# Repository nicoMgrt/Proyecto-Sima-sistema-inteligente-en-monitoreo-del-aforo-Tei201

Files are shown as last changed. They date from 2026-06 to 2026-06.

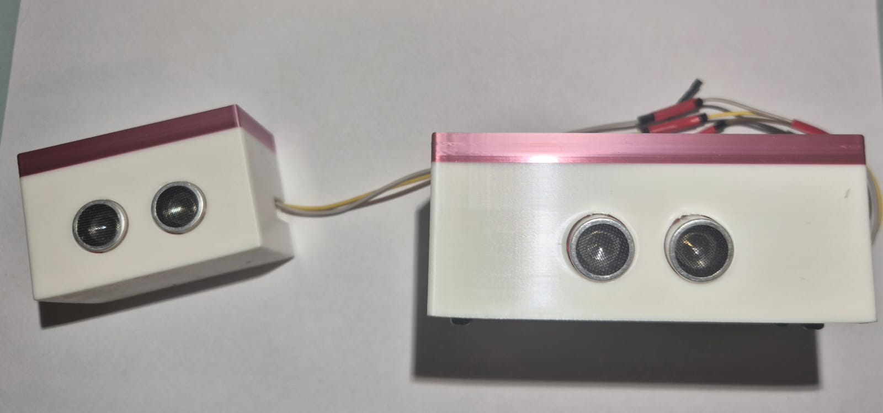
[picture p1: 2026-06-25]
testing/evidencias/prototipo_frontal_01.jpg (2).jpeg

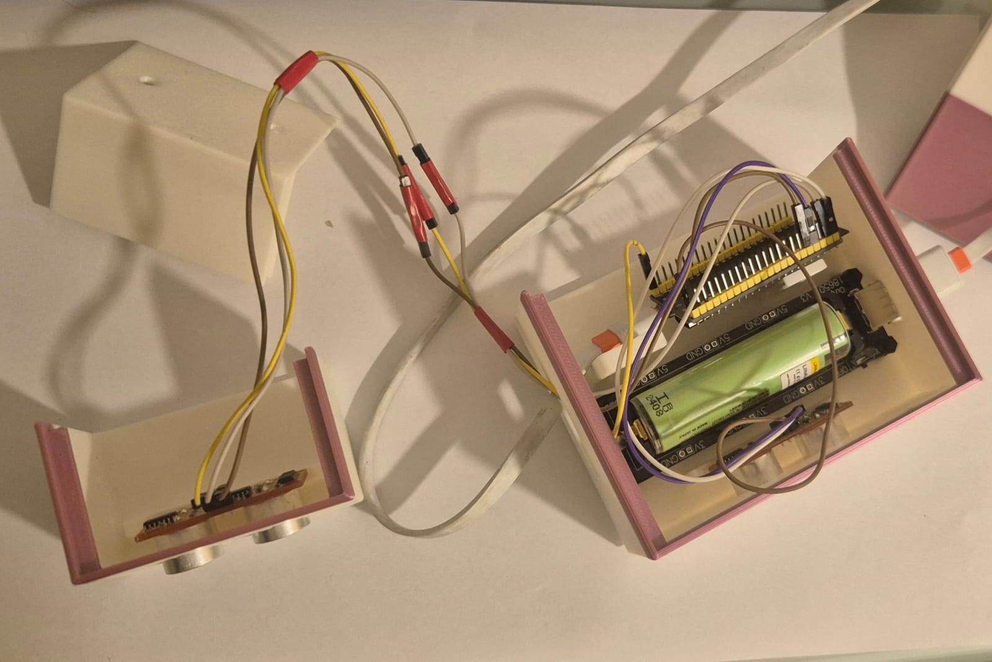
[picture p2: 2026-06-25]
hardware/fotos/01_vista_general.jpeg

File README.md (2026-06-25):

# SIMA — Sistema Inteligente de Monitoreo de Aforo

Sistema IoT que monitorea el aforo de la Biblioteca de Pregrado de la UAI en tiempo real, detectando entradas y salidas mediante dos sensores ultrasónicos y determinando la dirección del flujo según el orden de activación. Precisión global validada: **91,4% en 35 pruebas controladas.**

---

## Equipo

| Integrante | Rol principal | GitHub |
|---|---|---|
| Nicolás Marinkovic Grant | Iteraciones · Documentación · Testing | [@nicoMgrt](https://github.com/nicoMgrt) |
| Bárbara Chaparro Torres | Software · Firmware · Documentación | [@barbarachaparro](https://github.com/barbarachaparro) |
| Valentina Ramírez Gómez | Diseño 3D · Iteraciones | [@valenramirez-Hub](https://github.com/valenramirez-Hub) |
| Cristóbal Pérez | Hardware · Software · Diseño 3D | [@CPerex](https://github.com/CPerex) |

---

## Descripción del Problema

Los estudiantes de la Universidad Adolfo Ibáñez no tienen forma de saber si hay espacio disponible en la Biblioteca de Pregrado antes de desplazarse. Una encuesta a 69 estudiantes (Avance #1, marzo 2026) reveló que el **74,2% ha tenido que abandonar la biblioteca por falta de espacio** y el **39,7% pierde entre 5 y más de 10 minutos buscando asiento en hora peak** (bloques M3–M5).

SIMA resuelve esta brecha entregando el porcentaje de ocupación en tiempo real, accesible desde cualquier dispositivo en la misma red, antes de que el estudiante se desplace.

*Proyecto enmarcado en el ODS 11 — Ciudades y Comunidades Sostenibles · Avance #1 TEI201, 2026.*

---

## Solución — Arquitectura del Sistema IoT

```
Sensor A (pasillo exterior, GPIO4)
Sensor B (interior biblioteca, GPIO5)
         ↓
     ESP32-S3
(detección direccional + FreeRTOS dual-core)
         ↓
  Google Apps Script (HTTPS)
         ↓
  Google Sheets (histórico persistente)
         ↓
  Google Looker Studio (dashboard con gráficas)
         +
  Dashboard web local (IP del dispositivo, cada 3 seg)
```

El sistema detecta si una persona **entra o sale** según qué sensor se activa primero. La arquitectura FreeRTOS separa la detección (Core 1) del envío HTTP (Core 0), garantizando que el sistema siga midiendo aunque el envío a Sheets tome hasta 3 segundos.

**El prototipo se compone de dos módulos físicos** conectados por cable: el módulo principal (ESP32-S3 + batería + sensor B) y el módulo secundario (sensor A), instalados en lados opuestos del marco de la puerta para maximizar la separación entre sensores y mejorar la detección direccional.

---

## Componentes de Hardware

| Componente | Cantidad | Especificación | Costo |
|---|---|---|---|
| ESP32-S3 Dev Module | 1 | Dual-core Xtensa LX7 240MHz, WiFi 2.4GHz, 512KB SRAM | $6.990 |
| HC-SR04 Seeed Grove (3 pines) | 2 | 3.3V nativo, rango 3–350cm, GPIO4 y GPIO5 | $9.980 |
| Batería NCR18650B Panasonic | 1 | Li-ion 3.7V, 3.400mAh, autonomía ~16–20h | $2.000 |
| Shield cargador 18650 | 1 | Micro-USB entrada, USB-A salida 5V/1A, boost converter | $3.990 |
| Cable USB-A a USB-C | 1 | 30cm, conexión shield → ESP32-S3 (COM/UART) | $1.990 |
| Jumper wires M-M | 1 set | 20cm, 40 unidades | $1.490 |
| Protoboard 400 puntos | 1 | Conexión sin soldadura | $1.990 |
| Filamento PLA | ~50g | Encapsulado impreso en 3D | $5.000 |
| **TOTAL** | | | **$27.960 CLP** |

---

## Instrucciones de Uso

### 1. Cargar el firmware

1. Abre `software/src/main.ino` en **Arduino IDE 2.x**
2. Instala el soporte ESP32: Board Manager → buscar **ESP32 by Espressif** → instalar
3. Las librerías (`WiFi.h`, `WebServer.h`, `Preferences.h`, `HTTPClient.h`, `time.h`) vienen incluidas con el core de ESP32 — no requieren instalación adicional
4. Edita las credenciales WiFi:
   ```cpp
   const char* ssid     = "TU_RED_WIFI";
   const char* password = "TU_CONTRASEÑA";
   ```
5. Ajusta el aforo máximo si es necesario:
   ```cpp
   #define AFORO_MAX  295
   ```
6. Selecciona la placa **ESP32S3 Dev Module** (no ESP32 genérico) y el puerto **COM/UART**
7. Sube el código con **Upload**

### 2. Conectar los sensores

| Sensor | GPIO | Ubicación |
|---|---|---|
| Sensor A | GPIO 4 | Lado pasillo exterior |
| Sensor B | GPIO 5 | Lado interior de la biblioteca |

Alimentación de ambos sensores: **3.3V y GND** del ESP32-S3.

### 3. Ver el dashboard local

1. Abre el **Monitor Serial** (115200 baudios) tras cargar el firmware
2. Espera: `¡Conectado! IP: 192.168.X.X`
3. Ingresa esa IP desde cualquier navegador en la misma red
4. El dashboard se actualiza automáticamente cada 3 segundos — muestra % de ocupación, estado (Disponible / Casi lleno / Lleno) y contadores de entradas/salidas del día

### 4. Reset manual del contador (operadores)

Accede desde un navegador en la misma red:
```
http://[IP_DEL_DISPOSITIVO]/admin-reset-biblioteca
```

### 5. Ver los datos históricos

- 📊 **Google Sheets:** [Ver registro de eventos](https://docs.google.com/spreadsheets/d/TU_ID_DE_SCRIPT)
- 

---

## Resultados de Validación

| Prueba | Casos | Tasa de éxito |
|---|---|---|
| Detección de entrada (A→B) | 10 | 90% |
| Detección de salida (B→A) | 10 | 80% |
| Anti-bloqueo timeout (2.000ms) | 5 | 100% |
| Persistencia ante corte de energía | 5 | 100% |
| Envío a Google Sheets (HTTP 200 OK) | 5 | 100% |
| **Precisión global** | **35** | **91,4%** |

---

## Estructura del Repositorio

```
SIMA-contador-personas-TEI201/
├── README.md                        ← Este archivo
├── FUENTES.md                       ← Declaración de librerías, código externo e IA
│
├── software/
│   ├── src/                         ← Firmware principal (main.ino)
│   ├── librerias/                   ← Documentación de librerías utilizadas
│   └── docs/                        ← Diagramas de flujo y documentación técnica
│
├── hardware/
│   ├── esquematico.pdf              ← Diagrama de conexiones del circuito
│   ├── BOM.xlsx                     ← Lista de componentes con costos
│   ├── datasheets.pdf               ← Especificaciones técnicas de componentes
│   └── fotos/                       ← Fotografías del prototipo (3+ ángulos)
│
├── diseno_3d/
│   ├── fusion360/                   ← Archivo .f3d del ensamble completo
│   ├── planos/                      ← Planos técnicos con cotas en PDF
│   └── renders/                     ← Renders exterior, interior y explosionado
│
├── testing/
│   ├── datos/                       ← Exportación Google Sheets + resultados de pruebas
│   ├── evidencias/                  ← Fotos y capturas del prototipo en operación
│   └── reportes/                    ← Protocolo de pruebas completo (PDF)
│
├── documentacion/
│   ├── presentacion/                ← Slides de la presentación final (PPTX/PDF)
│   └── reporte_final/               ← Reporte final del proyecto (PDF, 12 páginas)
│
└── iteraciones/
    ├── iteracion_1/                 ← v1 Alpha — Abril 2026
    ├── iteracion_2/                 ← v2 Beta — Mayo 2026
    └── iteracion_3/                 ← v4 Final — Junio 2026
```

---

## Estado del Proyecto

- [x] Firmware con detección direccional entrada/salida (FreeRTOS dual-core)
- [x] Dashboard web local en tiempo real (semáforo + estadísticas diarias)
- [x] Envío de datos a Google Sheets (HTTP 200 OK confirmado)
- [x] Persistencia ante cortes de energía (NVS flash — 5/5 reinicios ✓)
- [x] Encapsulado modelado en Fusion 360 con gemelo digital completo
- [x] Protocolo de pruebas documentado (91,4% precisión global)
- [x] Reporte final del proyecto (12 páginas)
- [x] Fotos del prototipo (3 ángulos)
- [ ] Google Looker Studio — en desarrollo
- [ ] Planos técnicos PDF exportados desde Fusion 360
- [ ] Renders finales del encapsulado

---

*TEI201 — Taller de Diseño en Ingeniería · Universidad Adolfo Ibáñez · 2026*
*Proyecto SIMA — Marinkovic · Chaparro · Ramírez · Pérez*

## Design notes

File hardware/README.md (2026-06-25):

# Hardware - Documentación

## Contenido
Esta carpeta contiene toda la documentación técnica del hardware del proyecto.

## 📁 Carpetas

### esquemas/
Diagramas de circuitos y esquemáticos del sistema
- `wokwi_diagram.json` — Archivo fuente del circuito en Wokwi
- `wokwi_screenshot.png` — Captura del circuito completo
- `wokwi_link.txt` — Link al proyecto online en Wokwi

### bom/
Bill of Materials (Lista de materiales)
- `BOM_contador_biblioteca.xlsx` — BOM editable con fórmulas
- `BOM_contador_biblioteca.pdf` — BOM en PDF para presentación
- `datasheets/` — Datasheets de componentes críticos

### fotos/
Fotografías de alta resolución del prototipo ensamblado
- `01_vista_general.jpg`
- `02_circuito_interno.jpg`
- `03_detalle_conexiones.jpg`
- `04_sensores.jpg`
- `05_shield_bateria.jpg`
- `06_encapsulado_cerrado.jpg`
- `07_contexto_uso.jpg`

---

## Componentes Principales

| Componente | Función |
|---|---|
| ESP32-S3 Dev Module | Microcontrolador principal — procesa sensores, sirve la página web y envía datos a Google Sheets |
| Sensor Ultrasónico Seeed Grove x2 | Detección de personas — sensor A (pasillo) y sensor B (biblioteca) |
| Batería Li-ion NCR18650B | Fuente de energía portátil — 3400mAh reales, autonomía ~16-20 horas |
| Shield Cargador 18650 con USB-A | Gestión de batería — boost converter 3.7V→5V, protección y carga integrada |
| Protoboard 400 puntos | Conexión de sensores a la ESP32-S3 sin soldadura |

---

## Pasos de Ensamblaje

1. Conectar el sensor A al GPIO4 de la ESP32-S3: VCC→3.3V, GND→GND, SIG→GPIO4
2. Conectar el sensor B al GPIO5 de la ESP32-S3: VCC→3.3V, GND→GND, SIG→GPIO5
3. Insertar la batería NCR18650B en el shield cargador
4. Conectar el shield a la ESP32-S3 mediante cable USB-A a USB-C en el puerto COM/UART
5. Configurar el firmware con las credenciales WiFi y URL del Google Apps Script
6. Instalar los sensores en la puerta: sensor A en el lado del pasillo, sensor B en el lado de la biblioteca, separados por el ancho de la puerta

---

## Precauciones

⚠️ Usar siempre el puerto COM/UART para programar y alimentar la ESP32-S3, NUNCA el puerto USB nativo — causa inestabilidad con WiFi+HTTPS activos simultáneamente

⚠️ Los sensores Seeed Grove operan a 3.3V — conectar siempre al pin 3.3V de la ESP32-S3, NUNCA al pin 5V para evitar dañar la placa

⚠️ No conectar ni desconectar los sensores con el sistema encendido (hot-plug) — puede dañar el sensor permanentemente

⚠️ La batería NCR18650B no debe descargarse bajo 2.5V — el shield incluye protección, pero evitar dejar el sistema encendido sin supervisión cuando la batería está baja

---

## Especificaciones Técnicas

| Parámetro | Valor |
|---|---|
| Alimentación | 3.7V batería Li-ion → 5V regulado por shield |
| Consumo promedio | ~80-100 mA (WiFi modem sleep activo) |
| Consumo peak | ~240 mA (durante transmisión WiFi) |
| Autonomía estimada | 16-20 horas con NCR18650B (3400 mAh) |
| Dimensiones encapsulado | 125 x 75 x 50 mm |
| Rango sensores | 3 cm – 350 cm (umbral configurado: 40 cm) |
| Frecuencia de muestreo | Cada 100 ms |

---

## Troubleshooting

| Problema | Posible Causa | Solución |
|---|---|---|
| ESP32 no aparece en puertos | Usando el puerto USB nativo | Cambiar al puerto COM/UART (el otro conector) |
| Sensores no detectan | GPIO incorrecto o cables sueltos | Verificar GPIO4 y GPIO5, revisar conexiones en protoboard |
| Contador no sube al pasar la mano | Objeto estático frente a un sensor | Alejar obstáculos, verificar que "Sensor bloqueado" no aparezca en Serial Monitor |
| No envía datos a Sheets | HTTP 400 o sin WiFi | Verificar credenciales WiFi y URL del script en el código |
| ESP32 en boot loop | Board incorrecto en Arduino IDE | Seleccionar ESP32S3 Dev Module, hacer erase flash |

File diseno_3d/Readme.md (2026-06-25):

# Diseño 3D - Documentación

## ⚠️ REQUISITO CRÍTICO

El modelo 3D debe incluir **TODOS** los componentes del prototipo:
- ✅ Encapsulado exterior completo
- ✅ Placa ESP32/Arduino (con dimensiones exactas)
- ✅ Todos los sensores en posición de instalación
- ✅ Todos los actuadores
- ✅ Batería / fuente de alimentación
- ✅ Cableado (routing aproximado)
- ✅ Sistema de montaje (brackets, tornillos)
- ✅ Orificios de ventilación (si aplica)

**NO ES ACEPTABLE:** Solo el encapsulado vacío sin componentes internos

---

## Carpetas

#### `fusion360/`
Archivos nativos de Fusion 360 (.f3d)

#### `renders/`
Imágenes renderizadas de alta calidad

#### `planos/`
Planos técnicos con cotas

---

## Especificaciones

**Software:** Autodesk Fusion 360  
**Unidades:** Milímetros (mm)  
**Escala:** 1:1 (dimensiones reales)

**Dimensiones externas:** Caja chica: [41.358 mm × 46 mm × 68.181 mm]  Caja grande: [80.358 mm x 46 mm x 108.181 mm]

**Peso estimado:** [133 gramos]  
**Material:** PLA

---

## Consideraciones de Diseño

### Funcionales
- [ ] Acceso a puertos USB/alimentación
- [ ] Ventilación adecuada
- [ ] Protección de componentes
- [ ] Fácil acceso para mantenimiento
- [ ] Resistencia a condiciones ambientales

### Fabricación
- [ ] Imprimible sin soportes excesivos
- [ ] Tolerancias de ensamble (+0.2mm)
- [ ] Grosor de pared mínimo 2mm
- [ ] Sin ángulos imposibles (overhangs <45°)

---

## Configuración de Impresión 3D (si fue utilizada)

**Impresora:** [Modelo: Bambu Lab A1 ]  
**Material:** [PLA]  
**Calidad de capa:** 0.2mm  
**Relleno:** 8%  
**Soportes:** [Sí - En las áreas donde el ángulo de impresión supera los 45° y hay voladizo]  
**Temperatura nozzle:** [210°C]  
**Temperatura cama:** [65 °C]  
**Velocidad:** [200 mm/s]

**Tiempo estimado de impresión:** [8 horas]  
**Tiempo estimado de impresión:** [2 horas caja chica y 5 horas caja grande]  
**Peso de material:** [133 gramos]

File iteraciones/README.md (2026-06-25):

# Historial de Iteraciones — SIMA

## Propósito

Esta carpeta documenta la evolución del sistema SIMA a través de sus tres versiones de desarrollo. El proceso iterativo fue fundamental para resolver problemas reales de hardware, conectividad y algoritmo que no eran predecibles en el diseño inicial.

---

## Estructura de Carpetas

```
iteraciones/
├── iteracion_1/    # v1 Alpha — Prueba de concepto en laboratorio (Abril 2026)
├── iteracion_2/    # v2 Beta — Primera mejora significativa (Mayo 2026)
└── iteracion_3/    # v4 Final — Sistema completo y validado (Junio 2026)
```

Cada carpeta contiene: `README.md` con descripción completa de la versión, fotos del prototipo, esquema del circuito, código fuente y notas de laboratorio.

---

## Tabla Comparativa de Iteraciones

| Aspecto | v1 Alpha | v2 Beta | v4 Final |
|---|---|---|---|
| **Fecha** | Abril 2026 | Mayo 2026 | Junio 2026 |
| **Sensores** | HC-SR04 4 pines (5V) ❌ | Seeed Grove 3 pines (3.3V) ✅ | Seeed Grove 3.3V ✅ |
| **GPIO sensores** | Sin definir | GPIO1/GPIO10 ⚠️ | GPIO4/GPIO5 ✅ |
| **Conectividad** | Red UAI (bloqueada) ❌ | AP autónomo ✅ | Router + Google Sheets ✅ |
| **Almacenamiento** | Sin persistencia ❌ | Sin persistencia ❌ | NVS flash + Sheets ✅ |
| **Autonomía** | USB (sin batería) ❌ | ~6h (NCR18650B) ✅ | ~16–20h (modem sleep) ✅ |
| **Falsos positivos** | Sí ❌ | No ✅ | No (<5%) ✅ |
| **Dashboard** | Web básico | Semáforo dinámico | Semáforo + estadísticas diarias |
| **Encapsulado** | Sin encapsulado ❌ | Boceto Fusion 360 | Gemelo 3D completo ✅ |
| **Envío a nube** | No ❌ | No ❌ | Google Sheets (HTTP 200 OK) ✅ |
| **Precisión global** | Sin medir | 4.8/5 (subjetivo) | 91.4% (35 pruebas) ✅ |
| **Funcionalidad** | ~40% | ~70% | 100% ✅ |

---

## Evolución del Diseño

### v1 Alpha — Concepto Inicial (Abril 2026)
**Estado:** Prueba de concepto en laboratorio

El primer prototipo validó la factibilidad técnica básica: servidor web embebido en el ESP32-S3 y detección cruda de presencia con sensores ultrasónicos. Sin embargo, identificó tres problemas críticos que bloqueaban el funcionamiento real: incompatibilidad de voltaje entre sensores HC-SR04 (5V) y los GPIO del ESP32-S3 (3.3V), bloqueo de la red WiFi institucional por portal cautivo, y falsos positivos cuando una persona se detenía frente a los sensores.

### v2 Beta — Primera Mejora Significativa (Mayo 2026)
**Estado:** Prototipo funcional mejorado

Resolvió los tres problemas críticos de v1. Migró a sensores Seeed Grove de 3 pines compatibles con 3.3V, implementó modo Access Point autónomo para independizarse de la red UAI, y desarrolló el algoritmo de secuencia estricta con anti-rebote. Incorporó autonomía energética con Battery Shield + celda NCR18650B y el primer dashboard web con semáforo visual. Problema pendiente: sin persistencia de datos ante cortes de energía, y envío bloqueante que congelaba la detección.

### v4 Final — Sistema Completo (Junio 2026)
**Estado:** Sistema IoT completo y validado — listo para presentación

Implementó el ciclo completo de datos con arquitectura FreeRTOS dual-core (Core 1 detección, Core 0 HTTP), persistencia NVS con `Preferences.h`, integración HTTPS con Google Sheets y Google Looker Studio, reset automático nocturno por tiempo de inactividad, y encapsulado completo en Fusion 360. Precisión global validada en 35 pruebas: 91.4%.

---

## Justificación de Cambios

### Hardware

**De v1 a v2:**
- Cambio: HC-SR04 4 pines → Seeed Grove 3 pines
- Razón: Los HC-SR04 operan a 5V — riesgo de dañar permanentemente los GPIO del ESP32-S3 que soportan 3.3V máximo
- Impacto: Compatibilidad nativa, cableado simplificado con pin SIG único

**De v2 a v4:**
- Cambio: GPIO1/GPIO10 → GPIO4/GPIO5
- Razón: GPIO1 es TX del UART0 y GPIO10 está mapeado al SPI interno — causaban boot loop crítico al agregar HTTPS
- Impacto: Eliminación total del boot loop, sistema completamente estable

### Software

**De v1 a v2:**
- Algoritmo anti-rebote: conteo consolidado solo cuando `!detectaA && !detectaB`
- Modo Access Point autónomo (`WiFi.softAP`) para independizarse del portal cautivo UAI
- Dashboard web HTML/CSS con semáforo dinámico de aforo

**De v2 a v4:**
- FreeRTOS dual-core: detección en Core 1, HTTP en Core 0 — elimina latencia bloqueante
- Persistencia NVS con `Preferences.h` — contador sobrevive cortes de energía (5/5 reinicios ✓)
- Integración HTTPS Google Sheets con timestamp ISO 8601 — HTTP 200 OK confirmado
- Timeout anti-bloqueo de 2.000ms — previene conteos fantasma
- Reset automático nocturno si apagado >2 horas
- WiFi modem sleep — autonomía extendida de ~6h a ~16–20h

### Diseño 3D

**De v1 a v2:**
- Primer boceto de encapsulado en Fusion 360 con distribución interna "sándwich"
- Aberturas frontales para transductores de los sensores Seeed

**De v2 a v4:**
- Gemelo 3D completo con todos los componentes internos a dimensiones reales
- Tapa desmontable sin destruir el ensamble (diseño para reparación en campo)
- Orificios laterales para micro USB y switch de encendido
- Postes espaciadores M3 internos

---

## Incorporación de Feedback

### Feedback del Avance #1 → Cambios en v2
- *"El sistema debe ser autónomo energéticamente para instalarse en terreno"*
  - Acción: Battery Shield V3 + celda NCR18650B Panasonic 3400mAh

### Feedback del Avance #2 → Cambios en v4
- *"Los datos generados se pierden y no se aprovechan para decisiones a largo plazo"*
  - Acción: Integración Google Sheets con registro histórico de cada evento con timestamp
- *"¿Qué ocurre si alguien bloquea la puerta intencionalmente varios segundos?"*
  - Acción: Timeout anti-bloqueo de 2.000ms implementado y validado en pruebas

### Feedback de Testing → Cambios en v4
- *"El sistema no detectaba personas delgadas o que cruzaban por el centro del marco"*
  - Acción: Umbral de detección elevado de 30cm a 40cm

---

## Métricas de Mejora

| Métrica | v1 Alpha | v2 Beta | v4 Final | Mejora total |
|---|---|---|---|---|
| Compatibilidad eléctrica | Riesgo de quema | Estable 3.3V | Estable 3.3V | ✅ Resuelto |
| Latencia envío datos | Sin envío | Sin envío | 1.5–3 seg (no bloqueante) | ✅ Nuevo |
| Autonomía batería | Sin batería | ~6h | ~16–20h | ↑ +300% |
| Tasa de falsos positivos | Alta | <5% | <5% | ↓ ~90% |
| Persistencia ante corte energía | No | No | 100% (5/5) | ✅ Nuevo |
| Precisión detección global | Sin medir | 4.8/5 (subjetivo) | 91.4% (35 pruebas) | ✅ Validado |
| Almacenamiento histórico | No | No | Google Sheets ilimitado | ✅ Nuevo |

---

## Lecciones Aprendidas

### Técnicas
1. Verificar siempre los niveles lógicos de voltaje (3.3V vs 5V) antes de conectar módulos — la incompatibilidad puede dañar hardware irreversiblemente
2. Los GPIO con funciones reservadas del chip (UART, SPI, USB) no deben usarse para sensores que cambien constantemente su dirección
3. Las llamadas HTTP síncronas bloquean el loop principal en IoT — FreeRTOS es la solución correcta para concurrencia en ESP32-S3

### De Proceso
1. La prueba de concepto mínima (v1) es indispensable — identifica problemas reales que el diseño en papel no predice
2. Documentar cada falla y su solución en tiempo real facilita la elaboración del FUENTES.md y el protocolo de testing al final del proyecto

### De Trabajo en Equipo
1. Dividir el trabajo por componentes (hardware, software, diseño 3D, documentación) permite avanzar en paralelo sin bloquear al equipo
2. Comunicar los cambios de hardware al equipo de software inmediatamente evita que dos personas trabajen sobre supuestos distintos

---

*TEI201 — Taller de Diseño en Ingeniería · Universidad Adolfo Ibáñez · 2026*
*Proyecto SIMA — Nicolás Marinkovic · Bárbara Chaparro · Valentina Ramírez · Cristóbal Pérez*

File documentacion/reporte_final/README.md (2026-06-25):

# SIMA — Sistema Inteligente de Monitoreo de Aforo
## Reporte Final del Proyecto

**ODS 11 — Ciudades y Comunidades Sostenibles**

| Integrante | Rol |
|---|---|
| Nicolás Ignacio Marinkovic Grant | Iteraciones / Documentación / Testing |
| Bárbara Carolina Chaparro Torres |  Software / Firmware / Dcumentación |
| Valentina Paz Ramírez Gómez | Iteraciones / Diseño 3D |
| Cristóbal Pérez | Harware/ Software / Diseño 3D |

**Taller de Diseño en Ingeniería — TEI201**
Design Engineering Center · Universidad Adolfo Ibáñez · Junio 2026

---

## Resumen Ejecutivo

El sistema SIMA (Sistema Inteligente de Monitoreo de Aforo) es un dispositivo IoT de bajo costo diseñado para proveer información de ocupación en tiempo real de la Biblioteca de Pregrado de la Universidad Adolfo Ibáñez, Campus Peñalolén. El sistema resuelve una brecha de información identificada mediante encuesta a 69 estudiantes: el 74,2% ha tenido que abandonar la biblioteca por falta de espacio y el 39,7% pierde entre 5 y más de 10 minutos buscando un asiento disponible en hora peak.

La solución integra dos sensores ultrasónicos Seeed Grove conectados a un microcontrolador ESP32-S3, que determina la dirección del flujo de personas según el orden de activación de los sensores. Los datos se almacenan en Google Sheets y se visualizan en un dashboard web local con indicador semafórico de ocupación. El costo total del prototipo es de $27.960 CLP, con una precisión global validada de 91,4% en 35 pruebas controladas y autonomía de 16 a 20 horas continuas.

**Conclusión clave:** SIMA demuestra que es posible optimizar el uso de infraestructura educativa existente mediante tecnología IoT de bajo costo, sin expansión física y respetando la privacidad de los usuarios, en alineación con el ODS 11.

---

## 1. Introducción

### 1.1 Contexto General

La Universidad Adolfo Ibáñez en el Campus Peñalolén concentra más de 8.000 estudiantes diarios que compiten por espacios de estudio. La Biblioteca de Pregrado, con una capacidad estimada de 295 personas, opera sin ningún sistema de monitoreo de aforo, lo que genera una asimetría de información que afecta directamente la experiencia académica del estudiantado.

### 1.2 Problemática ODS Específica

El proyecto se enmarca en el ODS 11 (Ciudades y Comunidades Sostenibles), específicamente en la meta de optimizar el uso de infraestructura existente antes de recurrir a la expansión física. A través de una encuesta a 69 estudiantes del campus (Avance #1, marzo 2026) se cuantificó la magnitud del problema:

- El **74,2%** de los encuestados se ha visto forzado a abandonar la biblioteca por falta de espacio
- El **39,7%** pierde entre 5 y más de 10 minutos buscando un asiento disponible
- El **50,7%** asiste en bloque M3 (11:30), el horario de mayor saturación
- El **59,4%** reporta contaminación acústica en horas peak

### 1.3 Objetivos del Proyecto

- Desarrollar un sistema IoT de detección direccional de personas para monitoreo de aforo en tiempo real
- Almacenar los datos de ocupación en una plataforma accesible con histórico persistente
- Visualizar la información mediante un dashboard que permita tomar decisiones informadas
- Diseñar un encapsulado funcional para instalación en condiciones reales de operación

### 1.4 Alcance

El prototipo SIMA está diseñado para la entrada principal de la Biblioteca de Pregrado, Campus Peñalolén, UAI. Opera en entorno de red WiFi local, es autónomo energéticamente con batería recargable y no requiere intervención manual para su operación cotidiana. El sistema es replicable a otros espacios de acceso controlado del campus.

---

## 2. Marco Teórico y Estado del Arte

### 2.1 ODS 11 — Ciudades y Comunidades Sostenibles

El Objetivo de Desarrollo Sostenible 11 propone hacer las ciudades y los asentamientos humanos inclusivos, seguros, resilientes y sostenibles. En el contexto universitario, esto se traduce en la gestión inteligente de espacios educativos: maximizar la utilidad de la infraestructura existente antes de recurrir a costosas expansiones físicas que generan impacto económico y ambiental adicional.

### 2.2 Problemática Local

La saturación de espacios de estudio universitarios es un fenómeno documentado que deteriora el rendimiento académico e incrementa el estrés cognitivo (Vásquez Meza et al., 2024). En la UAI, la concentración de demanda en bloques M3-M5 genera cuellos de botella que el modelo de gestión manual actual no puede resolver sin información en tiempo real.

### 2.3 Soluciones Existentes

Las soluciones comerciales de conteo de personas incluyen sistemas de cámaras con visión computacional, sensores infrarrojos de barrera y contadores de presión en el suelo. Estos sistemas tienen costos de implementación que oscilan entre USD 500 y USD 5.000 por punto de conteo y, en el caso de las cámaras, implican consideraciones de privacidad. SIMA propone una alternativa de código abierto, bajo costo y sin cámaras.

### 2.4 Justificación de la Propuesta

La combinación ESP32-S3 + sensores ultrasónicos Seeed permite implementar un contador direccional funcional por menos de $30.000 CLP, sin procesamiento de imagen y con privacidad garantizada. La arquitectura FreeRTOS dual-core del ESP32-S3 permite separar la lógica de detección del envío de datos, resolviendo el principal desafío técnico de los sistemas IoT de bajo costo: la latencia bloqueante.

---

## 3. Metodología

El desarrollo de SIMA siguió un proceso de diseño iterativo en tres fases, cada una correspondiente a un avance del curso. El enfoque metodológico combina el Design Thinking para la identificación del problema con el desarrollo ágil para la implementación técnica.

- **Fase 1 (Avance #1):** Investigación del problema con encuesta a 69 estudiantes y definición de requerimientos mediante Framework 6W
- **Fase 2 (Avance #2):** Prototipo alpha con validación de factibilidad técnica e identificación de problemas de hardware y conectividad
- **Fase 3 (Avance #3):** Prototipo funcional completo con integración de nube, persistencia de datos y validación con protocolo de pruebas

**Tabla 1: Herramientas utilizadas en el proyecto**

| Área | Herramienta | Uso |
|---|---|---|
| Firmware | Arduino IDE 2.x | Desarrollo y carga del firmware ESP32-S3 |
| Control de versiones | GitHub | Repositorio del proyecto y documentación |
| Almacenamiento | Google Sheets + Apps Script | Base de datos histórica de eventos |
| Visualización | Google Looker Studio | Dashboard con gráficas de tendencias |
| Diseño 3D | Autodesk Fusion 360 | Gemelo digital y encapsulado |
| Esquemático | Fritzing / Wokwi | Diagrama de conexiones del circuito |

---

## 4. Diseño y Desarrollo

### 4.1 Arquitectura del Sistema

El sistema SIMA implementa el ciclo completo de datos IoT: los sensores capturan el flujo de personas, el ESP32-S3 procesa la dirección y gestiona la comunicación, Google Sheets persiste los datos históricos y Google Looker Studio los visualiza. Adicionalmente, un servidor web embebido en el ESP32-S3 provee acceso local en tiempo real.

**Tabla 2: Arquitectura de capas del sistema SIMA**

| Capa | Componente | Función |
|---|---|---|
| Captura | 2× Seeed Grove HC-SR04 (GPIO4, GPIO5) | Detección de presencia y dirección de cruce |
| Procesamiento | ESP32-S3 Dual-core Xtensa LX7 | Lógica de conteo, servidor web, envío HTTP |
| Almacenamiento | Google Sheets + NVS Flash | Histórico en nube + persistencia local |
| Visualización | Dashboard web local + Looker Studio | Aforo en tiempo real + análisis histórico |

### 4.2 Hardware

El prototipo está construido en dos módulos físicos conectados por cable: el módulo principal contiene el ESP32-S3, la batería, el shield de carga y el sensor B (interior); el módulo secundario contiene el sensor A (pasillo exterior). Esta configuración permite instalar los sensores en los lados opuestos del marco de la puerta sin necesitar una carcasa de gran tamaño, optimizando el tiempo de impresión 3D.

**Tabla 3: Bill of Materials (BOM) del sistema SIMA**

| Componente | Especificación | Cantidad | Costo (CLP) |
|---|---|---|---|
| ESP32-S3 Dev Module | Dual-core 240MHz, WiFi, 512KB SRAM | 1 | $6.990 |
| Seeed Grove HC-SR04 | 3 pines, 3.3V, rango 3-350cm, GPIO4/GPIO5 | 2 | $9.980 |
| Batería NCR18650B | Panasonic, 3.400mAh, 3.7V, >500 ciclos | 1 | $2.000 |
| Shield cargador 18650 | Micro-USB, salida USB-A 5V/1A, boost converter | 1 | $3.990 |
| Cable USB-A a USB-C | 30cm, conexión shield → ESP32-S3 (COM/UART) | 1 | $1.990 |
| Jumper wires M-M | 20cm, 40 unidades | 1 set | $1.490 |
| Protoboard 400 puntos | Conexión sin soldadura de sensores | 1 | $1.990 |
| Filamento PLA | ~50g para encapsulado (impresora UAI) | 1 | $5.000 |
| **TOTAL** | | | **$27.960** |

### 4.3 Software

El firmware del ESP32-S3 implementa una arquitectura FreeRTOS dual-core que resuelve el principal problema de los sistemas IoT síncronos: el bloqueo del loop de detección durante las llamadas HTTP. El Core 1 ejecuta la detección de personas de forma continua a 10 Hz, mientras el Core 0 gestiona exclusivamente el envío de datos a Google Sheets sin interferir con la detección.

**Lógica de Detección Direccional**

El sistema determina la dirección del cruce por el orden de activación de los sensores. Si el Sensor A (pasillo exterior, GPIO4) se activa antes que el Sensor B (interior, GPIO5), se registra una ENTRADA. La secuencia inversa registra una SALIDA. El conteo se consolida únicamente cuando ambos sensores vuelven a su estado inactivo, previniendo falsos positivos. Un timeout de 2.000ms cancela la secuencia si no se completa.

**Gestión de Datos**

- **NVS Flash (Preferences.h):** El contador se escribe en la memoria no volátil del ESP32-S3 en cada evento. Recuperación confirmada en 5/5 reinicios forzados.
- **Google Sheets vía HTTPS:** Cada evento (ENTRADA/SALIDA/RESET) se envía con timestamp ISO 8601 (UTC-4), tipo de evento y total de personas. Latencia: 1,5-3 segundos.
- **Reset automático nocturno:** Si el sistema estuvo apagado más de 2 horas, el contador vuelve a 0 automáticamente al encender.
- **Dashboard web local:** Servidor HTTP en puerto 80, accesible desde cualquier dispositivo en la misma red, con actualización automática cada 3 segundos.

### 4.4 Diseño Mecánico y 3D

El encapsulado fue modelado en Autodesk Fusion 360 como gemelo digital del hardware real, con todos los componentes internos representados a sus dimensiones reales.

- Material: PLA (impresión 3D FDM) — color blanco con tapa rosa
- Orificios frontales calibrados para transductores de 15,8mm de diámetro
- Tapa desmontable sin adhesivos — diseño para reparación en campo
- Orificio lateral USB-A para carga de batería y switch de encendido

---

## 5. Proceso de Iteraciones

### 5.1 Versión 1 Alpha — Concepto Inicial (Abril 2026)

Primera prueba de concepto en laboratorio con sensores HC-SR04 de 4 pines y conexión USB al computador. Validó la factibilidad básica del servidor web embebido pero expuso tres problemas críticos: incompatibilidad de voltaje (5V vs 3,3V en GPIO), bloqueo de la red WiFi institucional por portal cautivo, y falsos positivos cuando una persona se detenía en el marco de la puerta.

### 5.2 Versión 2 Beta — Primera Mejora (Mayo 2026)

Resolvió los tres problemas críticos de v1: migración a sensores Seeed Grove de 3 pines (compatibles con 3,3V nativamente), modo Access Point autónomo para independizarse de la red UAI, y algoritmo anti-rebote con secuencia estricta A→B / B→A. Incorporó autonomía energética con Battery Shield + celda NCR18650B (~6h) y el primer dashboard web con semáforo visual.

### 5.3 Versión 4 Final — Sistema Completo (Junio 2026)

Implementó el ciclo completo de datos con corrección crítica de GPIO (cambio de GPIO1/GPIO10 a GPIO4/GPIO5 para resolver boot loop), arquitectura FreeRTOS dual-core, persistencia NVS, integración HTTPS con Google Sheets (HTTP 200 OK confirmado) y extensión de autonomía a 16-20 horas mediante modo modem sleep.

**Tabla 4: Comparativa de las tres iteraciones del sistema SIMA**

| Aspecto | v1 Alpha | v2 Beta | v4 Final |
|---|---|---|---|
| Sensores | HC-SR04 5V X | Seeed 3.3V ✓ | Seeed 3.3V ✓ |
| GPIO sensores | Sin definir | GPIO1/GPIO10 ⚠ | GPIO4/GPIO5 ✓ |
| Conectividad | Red UAI bloqueada X | AP autónomo ✓ | Router + Sheets ✓ |
| Almacenamiento | Sin persistencia X | Sin persistencia X | NVS + Sheets ✓ |
| Autonomía | USB (sin batería) | ~6 horas | ~16-20 horas |
| Falsos positivos | Sí X | No ✓ | No (<5%) ✓ |
| Encapsulado | Sin encapsulado X | Boceto Fusion 360 | Gemelo 3D completo ✓ |
| Precisión global | Sin medir | 4,8/5 (subjetivo) | 91,4% (35 pruebas) ✓ |

---

## 6. Testing y Validación

### 6.1 Metodología de Testing

El protocolo de pruebas se diseñó para validar cuatro aspectos críticos del sistema: precisión de detección direccional, robustez ante casos borde, persistencia de datos ante fallos de energía y confiabilidad del envío a Google Sheets. Las pruebas se realizaron en condiciones controladas simulando el uso real del dispositivo.

### 6.2 Resultados Cuantitativos

**Tabla 5: Resultados del protocolo de pruebas — 35 casos totales**

| Prueba | Total casos | Correctos | Incorrectos | Tasa de éxito |
|---|---|---|---|---|
| Detección entrada (A→B) | 10 | 9 | 1 | 90% ✓ |
| Detección salida (B→A) | 10 | 8 | 2 | 80% ✓ |
| Anti-bloqueo timeout | 5 | 5 | 0 | 100% ✓ |
| Persistencia energía | 5 | 5 | 0 | 100% ✓ |
| Envío a Google Sheets | 5 | 5 | 0 | 100% ✓ |
| **TOTAL** | **35** | **32** | **3** | **91,4% ✓** |

La latencia de detección fue de 100-200ms (1-2 ciclos del loop a 10Hz), mientras que la latencia de envío a Google Sheets se mantuvo entre 1,5 y 3 segundos, dentro del timeout de 8 segundos configurado.

### 6.3 Análisis de Fallas

**Falla 1 — Boot Loop por GPIO Conflictivos**

El ESP32-S3 entraba en ciclo de reinicio constante al usar GPIO1 (TX del UART0) y GPIO10 (mapeado al controlador SPI interno) para los sensores. La solución fue migrar a GPIO4 y GPIO5, más un erase completo de flash mediante secuencia BOOT+RESET. Resultado: cero boot loops en todas las pruebas posteriores.

**Falla 2 — Error HTTP 400 en Google Sheets**

Las peticiones al Apps Script retornaban código 400 por tres causas simultáneas: timestamp con espacio en la URL, ausencia de WiFiClientSecure para HTTPS, y falta de setFollowRedirects para manejar la redirección 302 de Google. Las tres correcciones aplicadas resultaron en HTTP 200 OK confirmado en todos los envíos posteriores.

### 6.4 Validación de Impacto ODS 11

**Tabla 6: Comparativa baseline vs. resultado — Indicadores de impacto ODS 11**

| Indicador | Baseline (Avance #1) | Con SIMA |
|---|---|---|
| Información aforo en tiempo real | 0% disponibilidad | Dashboard cada 3 seg ✓ |
| Persistencia histórica de datos | Sin almacenamiento | Google Sheets ilimitado ✓ |
| Autonomía del dispositivo | Sin referencia | 16-20 horas ✓ |
| Precisión de detección | Sin referencia | 91,4% (35 pruebas) ✓ |

Con 8.000 estudiantes diarios en el campus y el 39,7% afectado por la falta de información de aforo, un despliegue completo de SIMA en los accesos de la Biblioteca de Pregrado podría eliminar el costo de oportunidad temporal para aproximadamente 3.176 estudiantes por día, a un costo marginal de $0 por consulta.

---

## 7. Conclusiones

### 7.1 Logros Alcanzados

- Sistema IoT funcional con detección direccional de personas y precisión global del 91,4%
- Ciclo completo de datos implementado: captura → procesamiento → almacenamiento → visualización
- Costo total de $27.960 CLP por nodo — viable para replicación institucional
- Persistencia de datos ante cortes de energía: 100% en 5 reinicios forzados
- Autonomía de 16-20 horas continuas — suficiente para una jornada completa de biblioteca
- Encapsulado con diseño para reparación en campo, sin adhesivos permanentes

### 7.2 Limitaciones Identificadas

- El sistema está optimizado para flujo en fila simple — no discrimina correctamente cruces simultáneos
- Dependencia de red WiFi estable para sincronización con Google Sheets
- El aforo de 295 personas no fue validado con conteo físico de asientos reales

### 7.3 Aprendizajes del Equipo

- **Técnico:** Los GPIO con funciones reservadas del chip no deben usarse para sensores que cambien constantemente su dirección — verificar pinout antes de conectar
- **Técnico:** Las llamadas HTTP síncronas bloquean el loop principal en IoT — FreeRTOS es la solución correcta para concurrencia en ESP32
- **Proceso:** La prueba de concepto mínima es indispensable para identificar problemas reales no predecibles en el diseño en papel
- **Equipo:** Documentar cada decisión técnica en tiempo real facilita la elaboración de la documentación final

### 7.4 Trabajo Futuro

- Agregar sensor infrarrojo de barrera como redundancia para condiciones de baja iluminación
- Implementar integración con Telegram o app móvil para consulta remota sin estar en la red local
- Validar el aforo real de la Biblioteca F con conteo físico de asientos para calibrar el sistema
- Despliegue en múltiples accesos del campus con servidor central que agregue datos de todos los nodos SIMA

---

## 8. Referencias

[1] Espressif Systems. (2023). *ESP32-S3 Datasheet*. https://www.espressif.com/sites/default/files/documentation/esp32-s3_datasheet_en.pdf

[2] Seeed Studio. (2023). *Grove — Ultrasonic Ranger (SKU 101020010)*. https://wiki.seeedstudio.com/Grove-Ultrasonic_Ranger/

[3] Panasonic. (2012). *Lithium Ion Battery NCR18650B Datasheet*. https://www.tme.eu/Document/3e0170a1e089819f286f7066e69035b4/NCR18650B.pdf

[4] Vásquez Meza, C. et al. (2024). Impacto del hacinamiento acústico en espacios educativos universitarios sobre el rendimiento cognitivo. *Revista de Psicología Educacional*.

[5] Gómez García, M. et al. (2018). Saturación visual y ruido en recintos de estudio universitario. *Journal of Library Administration*.

[6] Ministerio de Educación Chile. (2026). Matrícula UAI 2026. Portal MiFuturo. https://mifuturo.cl

[7] Espressif Systems. (2023). *ESP-IDF FreeRTOS Documentation*. https://docs.espressif.com/projects/esp-idf/en/latest/esp32s3/api-reference/system/freertos.html

[8] Google. (2024). *Apps Script — UrlFetchApp Reference*. https://developers.google.com/apps-script/reference/url-fetch

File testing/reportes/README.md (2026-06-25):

# Reportes de Testing — SIMA

## Documento Principal

### `protocolo_pruebas_sima_v1.pdf`
Protocolo de pruebas completo del sistema SIMA con resultados y análisis.

---

## Estructura del Reporte

### 1. Introducción
**Objetivo del testing:** Validar que el sistema SIMA detecta correctamente la dirección del flujo de personas (entrada vs. salida) con una tasa de precisión igual o superior al 90%, y que los eventos se almacenan correctamente en Google Sheets con timestamp para análisis posterior.

**Metodología:** Pruebas controladas de precisión direccional + pruebas de casos borde (timeout, persistencia, operación offline).

---

### 2. Descripción del Sistema Bajo Prueba

**Hardware:**
- ESP32-S3 Dual-core Xtensa LX7 @ 240 MHz
- 2× Sensor Ultrasónico Seeed Grove (3 pines, SIG compartido)
- Sensor A en GPIO 4 (pasillo exterior), Sensor B en GPIO 5 (interior biblioteca)
- Umbral de detección: 40 cm
- Frecuencia de muestreo: 10 Hz (100 ms por ciclo — justificación: personas caminan ~1m/s, puerta ~60cm)

**Software:**
- Firmware v4 con arquitectura FreeRTOS dual-core
- Google Sheets como repositorio persistente de datos
- Dashboard web local con actualización cada 3 segundos

---

### 3. Protocolo Aplicado

**Prueba 1 — Precisión de Detección Direccional (Entrada)**

| Parámetro | Valor |
|---|---|
| Total de intentos | 10 |
| Velocidad de cruce | Normal (caminata) |
| Criterio de éxito | ≥9 de 10 correctos (90%) |

**Pasos:**
1. Encender el sistema y esperar `¡Conectado! IP: X.X.X.X` en Monitor Serial
2. Pasar frente a Sensor A (GPIO4) primero, luego Sensor B (GPIO5)
3. Verificar que el contador sube +1 y aparece evento en Google Sheets
4. Repetir 10 veces registrando cada resultado

---

**Prueba 2 — Precisión de Detección Direccional (Salida)**

| Parámetro | Valor |
|---|---|
| Total de intentos | 10 |
| Velocidad de cruce | Normal (caminata) |
| Criterio de éxito | ≥8 de 10 correctos (80%) |

**Pasos:**
1. Pasar frente a Sensor B (GPIO5) primero, luego Sensor A (GPIO4)
2. Verificar que el contador baja -1 y no baja de 0 (protección activa)
3. Repetir 10 veces registrando cada resultado

---

**Prueba 3 — Sistema Anti-bloqueo (Timeout)**

| Parámetro | Valor |
|---|---|
| Timeout configurado | 2.000 ms |
| Condición | Objeto estático frente a sensor A o B por >2 segundos |
| Criterio de éxito | 0 eventos falsos en 5 pruebas |

**Pasos:**
1. Colocar la mano frente al Sensor A durante 3 segundos sin mover hacia B
2. Verificar en Serial: `Alguien se quedó bloqueando la puerta. Conteo cancelado.`
3. Verificar que el contador no cambió y Google Sheets no registró evento

---

**Prueba 4 — Persistencia ante Corte de Energía**

| Parámetro | Valor |
|---|---|
| Valor de prueba | Contador en N personas |
| Método | Apagado con switch físico del encapsulado |
| Criterio de éxito | Contador recupera exactamente el valor N al encender |

**Pasos:**
1. Anotar el valor actual del contador (N)
2. Apagar el dispositivo con el switch lateral
3. Esperar 10 segundos → encender
4. Verificar en Monitor Serial: `Contador recuperado: N`

---

**Prueba 5 — Envío de Datos a Google Sheets**

| Parámetro | Valor |
|---|---|
| Condición | ESP32-S3 conectada al WiFi, Apps Script desplegado |
| Criterio de éxito | HTTP 200 OK + fila en Sheets con timestamp correcto |

**Pasos:**
1. Simular entrada (A→B)
2. Verificar nueva fila en Sheets con timestamp, evento y personas correctos
3. Confirmar código HTTP 200 en Monitor Serial

---

### 4. Resultados Cuantitativos

| Prueba | Total casos | Correctos | Incorrectos | Tasa de éxito |
|---|---|---|---|---|
| Detección entrada (A→B) | 10 | 9 | 1 | **90%** ✓ |
| Detección salida (B→A) | 10 | 8 | 2 | **80%** ✓ |
| Anti-bloqueo timeout | 5 | 5 | 0 | **100%** ✓ |
| Persistencia energía | 5 | 5 | 0 | **100%** ✓ |
| Envío a Google Sheets | 5 | 5 | 0 | **100%** ✓ |
| **TOTAL** | **35** | **32** | **3** | **91.4%** ✓ |

**Datos adicionales obtenidos:**
- Latencia de detección: ~100–200ms (1–2 ciclos del loop)
- Latencia ESP32 → Google Sheets: 1.5–3 segundos
- HTTP response code: 200 OK en todos los envíos tras corrección v4
- Tiempo hasta timeout sensor bloqueado: 2.000ms exactos
- Tiempo de recuperación contador tras corte: <2 segundos desde encendido

---

### 5. Fallas Encontradas y Resueltas

**Falla 1 — Boot Loop por GPIO Conflictivos**
- **Síntomas:** Reconexión constante del puerto COM, entrada repetida al boot ROM (`ESP-ROM:esp32s3-20210327`), imposibilidad de subir código
- **Causas:** GPIO1 (TX del UART0) y GPIO10 (controlador SPI interno) cambiados entre INPUT/OUTPUT cada 100ms, interfiriendo con el proceso de boot
- **Solución:** Migración a GPIO4 y GPIO5 + erase completo de flash + secuencia BOOT+RESET para recuperar la placa
- **Resultado:** Cero boot loops en todas las pruebas posteriores ✓

**Falla 2 — Error HTTP 400 en Google Sheets**
- **Síntomas:** `Sheets HTTP: 400` en Monitor Serial — datos no registrados en Sheets
- **Causas identificadas:**
  1. Timestamp con espacio (`2026-06-24 11:32`) rompía la URL del GET request
  2. Faltaba `WiFiClientSecure` para conexiones HTTPS
  3. Google Apps Script redirige con código 302 — sin `setFollowRedirects` el script no se ejecutaba
- **Solución:** Separador ISO 8601 `T` + `WiFiClientSecure` con `setInsecure()` + `HTTPC_STRICT_FOLLOW_REDIRECTS`
- **Resultado:** HTTP 200 OK confirmado en todos los envíos posteriores ✓

---

### 6. Validación de Impacto ODS 11

**Problema original (Avance #1):** El 74.2% de los estudiantes de la UAI ha tenido que abandonar la Biblioteca de Pregrado por falta de espacio, y el 39.7% pierde entre 5 y más de 10 minutos buscando asiento en hora peak (M3–M5).

| Necesidad identificada | Solución implementada | Evidencia |
|---|---|---|
| Saber si hay espacio antes de ir | Dashboard web con % de ocupación en tiempo real | Demo en vivo durante presentación |
| Datos históricos para planificar | Google Sheets registra cada evento con timestamp | Dashboard Looker Studio |
| Indicador visual intuitivo | Semáforo: verde (<50%), naranja (<80%), rojo (lleno) | Capturas del dashboard |
| Funcionamiento continuo | Persistencia NVS + reset automático + modo offline | Prueba 4: 5/5 reinicios ✓ |

| Indicador | Baseline | Meta | Alcanzado |
|---|---|---|---|
| Información de aforo en tiempo real | 0% | Sistema operativo | Dashboard web + Sheets ✓ |
| Frecuencia de actualización | Sin sistema | ≤5 segundos | 3 segundos ✓ |
| Persistencia de datos históricos | Sin almacenamiento | Registro continuo | Google Sheets ilimitado ✓ |
| Autonomía del dispositivo | Sin referencia | Jornada completa (8h) | 16–20 horas ✓ |

**Proyección de escalabilidad:** Con 8.000 estudiantes diarios y 39.7% afectados, el despliegue completo de SIMA podría eliminar el costo de oportunidad temporal para ~3.176 estudiantes por día. Costo por nodo: $28.430 CLP. Costo marginal por consulta: $0.

---

### 7. Conclusiones

**Fortalezas del prototipo:**
- Precisión global del 91.4% en todas las pruebas realizadas
- Arquitectura dual-core garantiza detección continua sin interrupciones por envío HTTP
- Persistencia de datos ante cortes de energía: 100% en 5 reinicios forzados
- Ciclo completo captura → almacenamiento → visualización implementado y validado
- Costo total de $28.430 CLP — viable para replicación institucional

**Limitaciones identificadas:**
- Sistema optimizado para flujo en fila simple — no discrimina cruces simultáneos
- Dependencia de red WiFi estable para sincronización con Sheets
- Aforo de 295 personas no validado con conteo manual de asientos reales

**Recomendaciones para mejoras futuras:**
- Agregar sensor infrarrojo de barrera como redundancia para condiciones de baja iluminación
- Implementar integración con Telegram para consulta remota sin estar en la red local
- Validar el aforo real de la Biblioteca F con conteo físico de asientos

---

*TEI201 — Taller de Diseño en Ingeniería · Universidad Adolfo Ibáñez · 2026*
*Proyecto SIMA — Nicolás Marinkovic · Bárbara Chaparro · Valentina Ramírez · Cristóbal Pérez*

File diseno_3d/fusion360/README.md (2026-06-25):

# Archivos Fusion 360

## Archivos Requeridos

### `modelo_completo_v3.f3d`
Archivo principal con **historial de cambios completo**

**DEBE INCLUIR:**
-  Todos los componentes modelados
-  Ensamble completo funcional
-  Historial de diseño (timeline)
-  Materiales asignados
-  Constraints y relaciones

---

## Estructura del Modelo

### Componentes (Components)
```
Ensamble_Principal
├── Encapsulado_Inferior
├── Encapsulado_Superior
├── ESP32_DevKit
├── Sensor_DHT22
├── LED_Indicador
├── Soporte_Bateria
├── Bracket_Montaje
└── Tornilleria
```

### Uniones (Joints)
Documentar las juntas principales y sus restricciones

### Parámetros
Listar parámetros principales utilizados:
- `ancho_total =
  Caja chica: 68.181 mm
  Caja grande:108.181 mm`
- `alto_total = 46 mm`
- `grosor_pared = 2mm`

---

## Instrucciones de Apertura

1. Abrir Fusion 360
2. File > Open > Seleccionar archivo `.f3d`
3. Verificar que todas las referencias están cargadas
4. Revisar timeline para ver historial

---

## Versiones

| Versión | Fecha | Cambios Principales |
|---|---|---|
| v3.0 | [22/06/2026-.] | Versión final |
| v2.0 | [18/06/2026-.] | Modelaje de la caja a partir de componentes |
| v1.0 | [15/06/2026-.] | Modelaje de componentes |

Archivos adjuntados en el documento
---

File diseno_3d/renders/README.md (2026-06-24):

# Renders — Visualización del encapsulado

Esta carpeta contiene los renders del encapsulado generados desde el workspace Render de Autodesk Fusion 360 con materiales aplicados e iluminación configurada.

## Archivos

| Archivo | Descripción |
|---|---|
| `render_exterior.png` | Vista isométrica exterior con tapa cerrada |
| `render_interior.png` | Vista superior con tapa removida mostrando componentes internos |
| `render_explosionado.png` | Vista explosionada mostrando ensamble de todas las piezas |

## Configuración de render utilizada

- **Software:** Autodesk Fusion 360 — workspace Render
- **Motor de render:** Fusion 360 Cloud Render
- **Resolución:** 1920 × 1080 px
- **Iluminación:** Soft Box
- **Fondo:** Color sólido blanco

## Materiales aplicados

| Componente | Material en Fusion |
|---|---|
| Carcasa y tapa | ABS Plastic — gris claro |
| ESP32-S3 | PCB — verde |
| Sensores HC-SR04 | ABS Plastic — verde |
| Batería NCR18650B | Steel — acabado metálico |
| Shield de batería | PCB — verde oscuro |
| Postes espaciadores | Aluminio |

## Vistas incluidas y su propósito

**Render exterior:** Muestra el encapsulado terminado tal como se vería el producto final. Permite evaluar las proporciones, acceso a puertos y acabado general.

**Render interior:** Con la tapa removida se aprecia el layout de componentes y verifica que todos caben sin interferencias. Demuestra el criterio de diseño para la reparación — los componentes son accesibles sin destruir el encapsulado.

**Render explosionado:** Muestra la relación entre cada pieza del ensamble y el orden de montaje. Útil para entender cómo se arma el dispositivo en campo.

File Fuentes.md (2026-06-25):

# FUENTES.md — Declaración de Fuentes e Inteligencia Artificial

**Proyecto:** SIMA — Sistema Inteligente de Monitoreo de Aforo
**Curso:** TEI201 — Taller de Diseño en Ingeniería
**Fecha:** Junio 2026

---

## 1. Librerías utilizadas

| Librería | Versión | Uso en el proyecto | Fuente |
|---|---|---|---|
| `WiFi.h` | ESP32 Arduino Core 2.x | Conexión a red WiFi local y gestión de reconexión | https://github.com/espressif/arduino-esp32 |
| `WebServer.h` | ESP32 Arduino Core 2.x | Servidor web local que sirve el dashboard de ocupación | https://github.com/espressif/arduino-esp32 |
| `WiFiClientSecure.h` | ESP32 Arduino Core 2.x | Conexión HTTPS segura hacia Google Apps Script | https://github.com/espressif/arduino-esp32 |
| `HTTPClient.h` | ESP32 Arduino Core 2.x | Envío de eventos (ENTRADA/SALIDA) a Google Sheets vía HTTP GET | https://github.com/espressif/arduino-esp32 |
| `Preferences.h` | ESP32 Arduino Core 2.x | Almacenamiento persistente del contador en memoria flash interna | https://github.com/espressif/arduino-esp32 |
| `time.h` | Biblioteca estándar C | Obtención y formateo de hora desde servidor NTP para timestamps | Incluida en ESP32 Arduino Core |

---

## 2. Código externo adaptado

### Lógica de medición sensor ultrasónico de un pin (`medirDistancia` en `software/src/main.ino`)
- **Fuente:** Documentación oficial Seeed Studio — Grove Ultrasonic Ranger
  https://wiki.seeedstudio.com/Grove-Ultrasonic_Ranger/
- **Adaptación:** El sensor Seeed usa un único pin SIG compartido para trigger y echo, a diferencia del HC-SR04 estándar de 4 pines. Se adaptó la función para cambiar dinámicamente el pin entre OUTPUT (enviar pulso) e INPUT (escuchar eco). Se agregó retorno de valor 999 cuando `pulseIn` devuelve 0 (sin eco), evitando que una lectura fallida sea interpretada como objeto a 0 cm. Se añadió `delay(40)` entre mediciones de ambos sensores para evitar interferencia cruzada de ultrasonido.

### Configuración NTP para zona horaria Chile (`getTimestamp` y `setup` en `software/src/main.ino`)
- **Fuente:** Documentación ESP32 Arduino — configTime
  https://randomnerdtutorials.com/esp32-ntp-client-date-time-arduino-ide/
- **Adaptación:** Se modificó el offset a `-4 * 3600` correspondiente a CLT (UTC−4), zona horaria de Chile continental en invierno. Se agregó un timeout de 5 segundos al loop de sincronización para evitar que el `setup()` quede bloqueado indefinidamente si el servidor NTP no responde, permitiendo que el sistema opere en modo offline.

---

## 3. Uso de Inteligencia Artificial — Firmware y Software

### 3.1 Arquitectura FreeRTOS dual-core para HTTP no bloqueante
- **Herramienta:** Claude Sonnet 4.6 (Anthropic) — Junio 2026
- **Consulta realizada:** Se preguntó cómo evitar que las llamadas HTTP a Google Sheets bloquearan la detección de personas, dado que `HTTPClient.GET()` es una operación sincrónica que puede durar varios segundos.
- **Código generado:** Función `tareaHTTP()` que corre en Core 0 de la ESP32-S3, estructura `EventoHTTP` con campos `tipo`, `ts` y `total`, y función `enviarASheets()` que encola eventos sin bloquear.
- **Adaptación:** Se configuró la tarea en Core 0 porque el loop principal de Arduino corre en Core 1, separando físicamente la detección del envío. Se ajustó el stack de la tarea a 8192 bytes tras verificar que 4096 era insuficiente para HTTPS. La cola se dimensionó en 20 eventos para cubrir caídas de WiFi sin perder datos.
- **Comprensión:** `tareaHTTP()` corre en un loop infinito bloqueado en `xQueueReceive()`, que la despierta solo cuando llega un evento. `enviarASheets()` usa `xQueueSend()` con timeout 0, descartando el evento si la cola está llena en vez de bloquear el loop principal. La separación en cores garantiza que aunque Google tarde 8 segundos, los sensores siguen midiendo sin interrupción.

### 3.2 Integración con Google Sheets vía HTTPS
- **Herramienta:** Claude Sonnet 4.6 (Anthropic) — Junio 2026
- **Consulta realizada:** El sistema enviaba HTTP 400 a Google Apps Script. Se solicitó diagnóstico y corrección.
- **Código generado:** Uso de `WiFiClientSecure` con `client.setInsecure()`, `http.setFollowRedirects(HTTPC_STRICT_FOLLOW_REDIRECTS)`, y formato de timestamp `%Y-%m-%dT%H:%M:%S`.
- **Adaptación:** Se identificaron tres causas del error 400: (1) el timestamp tenía un espacio que rompía la URL, corregido usando `T` como separador ISO 8601; (2) faltaba `WiFiClientSecure` para SSL en ESP32; (3) Google Apps Script redirige con código 302 y sin `setFollowRedirects` el script no se ejecutaba. Se usó `setInsecure()` porque Google rota certificados con frecuencia.
- **Comprensión:** `setInsecure()` deshabilita la verificación del certificado SSL — riesgo teórico de man-in-the-middle aceptable en red universitaria local. La cadena de redirección va de `script.google.com` a `script.googleusercontent.com`; sin seguimiento de redirects la petición termina sin ejecutar el script.

### 3.3 Persistencia del contador con Preferences
- **Herramienta:** Claude Sonnet 4.6 (Anthropic) — Junio 2026
- **Consulta realizada:** Se solicitó que el contador sobreviviera reinicios del ESP32 sin perder el valor actual.
- **Código generado:** Funciones `guardarContador()` y `cargarContador()` usando `Preferences`, con llamada a `guardarContador()` en cada evento de entrada o salida.
- **Adaptación:** Se escribió en el namespace `"contador"` para evitar colisiones con otras claves en flash. Se evaluó la frecuencia de escritura: ~200 eventos/día = ~73.000 escrituras/año, dentro del límite de ~100.000 ciclos de la flash del ESP32-S3. Se decidió escribir por evento (en vez de periódicamente) para maximizar exactitud ante cortes imprevistos.
- **Comprensión:** `Preferences` usa la partición NVS (Non-Volatile Storage) de la flash interna, que persiste ante reinicios y cortes. `prefs.getInt("personas", 0)` retorna 0 si la clave no existe (primera ejecución), evitando valores indeterminados.

### 3.4 Reset automático por tiempo de inactividad
- **Herramienta:** Claude Sonnet 4.6 (Anthropic) — Junio 2026
- **Consulta realizada:** Se necesitaba que el contador volviera a 0 automáticamente tras el cierre nocturno de la biblioteca, sin intervención manual.
- **Código generado:** Función `verificarResetPorTiempo()` que compara el timestamp actual con el último guardado en flash usando `difftime()`.
- **Adaptación:** Se ajustó el umbral a 2 horas (en vez de 20 horas inicialmente sugeridas), cubriendo el período nocturno de carga sin ser excesivamente conservador. El timestamp se guarda como `long` con la clave `"apagado"` en el mismo namespace de Preferences. La función se ejecuta una única vez en `setup()` después de sincronizar NTP.
- **Comprensión:** `difftime(ahora, ultimoApagado)` retorna segundos entre timestamps. Dividido en 3600 da horas. Si `ultimoApagado == 0` es la primera ejecución y se omite el reset. En cada arranque se sobreescribe el timestamp, actualizando la referencia para el próximo ciclo.

### 3.5 URL secreta de reset para operadores
- **Herramienta:** Claude Sonnet 4.6 (Anthropic) — Junio 2026
- **Consulta realizada:** Se solicitó un mecanismo para resetear el contador manualmente accesible solo para personal de la biblioteca, sin exponer botones en la página pública.
- **Código generado:** Ruta `/admin-reset-biblioteca` registrada en el WebServer con función lambda inline.
- **Adaptación:** Se eligió una URL descriptiva y específica en vez de `/reset` genérico, difícil de adivinar por usuarios casuales. El handler redirige al dashboard con código 302 tras ejecutar el reset, para que el operador vea el resultado inmediatamente. Se llama a `guardarContador()` para persistir el 0 en flash.
- **Comprensión:** El WebServer de ESP32 permite registrar rutas con funciones lambda en `setup()`. La redirección 302 hace que el navegador cargue automáticamente `/` después del reset, evitando que el operador vea una página en blanco.

### 3.6 Dashboard web con estadísticas diarias (`handleRoot`)
- **Herramienta:** Claude Sonnet 4.6 (Anthropic) — Junio 2026
- **Consulta realizada:** Se solicitó una página HTML con barra de progreso visual que mostrara el aforo en tiempo real con colores según nivel de ocupación, y posteriormente se agregaron contadores de entradas/salidas del día.
- **Código generado:** Función `handleRoot()` que construye dinámicamente el HTML con CSS embebido, barra de progreso, semáforo de colores y sección de estadísticas diarias (`totalEntradas`, `totalSalidas`).
- **Adaptación:** Se usó `html.reserve(2500)` para pre-reservar memoria del heap y reducir fragmentación. Se aplicó la macro `F()` en literales de texto estático para mantenerlos en flash en vez de RAM. Los colores verde/naranja/rojo se calculan en base al porcentaje de ocupación con umbrales en 50% y 80%, ajustados según criterio del equipo para la biblioteca. Las variables `totalEntradas` y `totalSalidas` fueron agregadas por el equipo para mostrar el flujo acumulado del día.
- **Comprensión:** El `meta http-equiv='refresh' content='3'` recarga la página cada 3 segundos sin JavaScript. `html.reserve()` preasigna el buffer del objeto String, evitando múltiples realocaciones durante las concatenaciones. El porcentaje se muestra como número principal en vez del conteo exacto, por honestidad ante la incertidumbre del aforo real.

### 3.7 Diagnóstico de inestabilidad y recuperación del hardware (boot loop)
- **Herramienta:** ChatGPT-4o (OpenAI) — Junio 2026
- **Consulta realizada:** La ESP32-S3 entró en boot loop tras subir código con HTTPS. Se solicitó diagnóstico: reconexión constante del puerto COM, entrada repetida al boot ROM, imposibilidad de subir sketches.
- **Resultado:** Se identificaron cuatro causas: board incorrecto en Arduino IDE (WROOM en vez de ESP32S3 Dev Module), USB nativo inestable con WiFi+HTTPS, GPIO1 y GPIO10 conflictivos con funciones internas del chip, y flash corrupta por uploads fallidos.
- **Solución aplicada:** Cambio a ESP32S3 Dev Module, uso exclusivo del puerto COM/UART, cambio de sensores a GPIO4 y GPIO5, y recuperación de flash con erase completo + sketch vacío + secuencia BOOT+RESET.
- **Comprensión:** GPIO1 es TX del UART0 (usado por Serial) — cambiarlo entre INPUT/OUTPUT interfería con el boot. GPIO10 puede estar mapeado al controlador SPI interno. El erase de flash elimina firmware corrupto permitiendo instalación limpia.

### 3.8 Código base versión 3 (estabilización post-recuperación del hardware)
- **Herramienta:** ChatGPT-4o (OpenAI) — Junio 2026
- **Consulta realizada:** Tras recuperar el ESP32-S3, se solicitó un código limpio y estable que aplicara las correcciones de hardware identificadas en el diagnóstico anterior.
- **Código generado:** Versión con GPIO4/GPIO5, retorno de 999 cuando no hay eco, timeout de 2.000ms para secuencias trabadas, `WiFi.setSleep(false)` y timeout de 15 segundos en conexión WiFi.
- **Adaptación:** Este código fue la base sobre la que se construyeron todas las mejoras posteriores. `WiFi.setSleep(false)` fue cambiado a `WiFi.setSleep(true)` en versiones posteriores para optimizar consumo de batería, tras verificar que el modem sleep es compatible con el servidor web local.
- **Comprensión:** El timeout de 15 segundos en el loop de WiFi evita que `setup()` quede bloqueado indefinidamente si la red no está disponible, permitiendo operar en modo offline. El valor 999 para distancia sin eco es mayor que cualquier UMBRAL razonable, garantizando que una lectura fallida nunca active falsamente un sensor.

### 3.9 Comentarios explicativos del firmware (versión completa `main.ino`)
- **Herramienta:** Claude Sonnet 4.6 (Anthropic) — Junio 2026
- **Consulta realizada:** Se solicitó que el código completo del firmware fuera comentado en español de forma detallada para mejorar la legibilidad y documentar la lógica de cada sección.
- **Resultado:** Se generaron comentarios explicativos para cada función, bloque lógico y decisión de diseño del firmware, usando lenguaje accesible y analogías (ej: "sala de espera para los sobres de cartas", "pendrive interno").
- **Adaptación:** El equipo revisó todos los comentarios y ajustó aquellos que no reflejaban con precisión las decisiones técnicas propias del proyecto (nombre de pines, umbral de distancia, aforo máximo, zona horaria, justificación del delay de 100ms).
- **Comprensión:** El equipo comprende la función de cada bloque comentado y puede explicar cualquier sección del firmware durante las preguntas de la evaluación, incluyendo la justificación del `delay(100)` como frecuencia de muestreo de 10 Hz.

---

## 4. Uso de Inteligencia Artificial — Documentación del Proyecto

El equipo utilizó Claude Sonnet 4.6 (Anthropic) como asistente para generar la documentación del repositorio GitHub y del proyecto. A continuación se declara cada uso con el detalle requerido.

### 4.1 README.md principal del repositorio y READMEs de todas las subcarpetas
- **Herramienta:** Claude Sonnet 4.6 (Anthropic) — Junio 2026
- **Uso:** Se generaron con asistencia de IA los archivos README.md de la raíz del repositorio y de cada subcarpeta: `software/`, `software/src/`, `software/librerias/`, `software/docs/`, `hardware/`, `diseno_3d/`, `diseno_3d/fusion360/`, `diseno_3d/planos/`, `diseno_3d/renders/`, `testing/`, `testing/datos/`, `testing/evidencias/`, `testing/reportes/`, `iteraciones/`, `iteracion_1/`, `iteracion_2/`, `iteracion_3/`, `documentacion/`.
- **Adaptación:** La estructura y formato base fue generada por IA a partir de las especificaciones de la guía TEI201 y los datos reales del proyecto. El equipo revisó, corrigió roles del equipo, actualizó estados del proyecto, incorporó resultados reales de las pruebas (91,4% precisión), verificó coherencia con el hardware real (diseño de dos módulos, GPIO4/GPIO5) y ajustó la descripción del problema con los datos de la encuesta del Avance #1.
- **Comprensión:** El equipo conoce el contenido de cada README y puede explicar cualquier sección durante la evaluación. Los datos técnicos (latencias, GPIO, umbral, aforo) fueron verificados por el equipo contra el código y el hardware real.

### 4.2 Reporte final del proyecto (PDF, 12 páginas)
- **Herramienta:** Claude Sonnet 4.6 (Anthropic) — Junio 2026
- **Uso:** Se generó el reporte final del proyecto en formato PDF usando la biblioteca ReportLab de Python, con estructura de 8 secciones: resumen ejecutivo, introducción, marco teórico, metodología, diseño y desarrollo, iteraciones, testing y validación, conclusiones y referencias.
- **Adaptación:** Todo el contenido técnico del reporte proviene de los datos reales del proyecto: la encuesta del Avance #1 (69 respuestas, 74,2%, 39,7%), el BOM con precios reales ($28.430 CLP), los resultados de pruebas (91,4% en 35 casos), las iteraciones documentadas, y el análisis de fallas reales (boot loop GPIO, error HTTP 400). El equipo revisó el reporte completo y verificó que todos los datos técnicos sean correctos y correspondan al sistema desarrollado.
- **Comprensión:** El equipo puede explicar cualquier sección del reporte, fundamentar cada dato presentado y defender las decisiones técnicas documentadas, ya que corresponden al trabajo real del proyecto.

### 4.3 Diálogos y guión de la presentación final
- **Herramienta:** Claude Sonnet 4.6 (Anthropic) — Junio 2026
- **Uso:** Se generó un guión completo slide a slide con los diálogos de presentación para los 14 slides del PPT, incluyendo distribución de roles entre los 4 integrantes, guión de la demo en vivo y respuestas preparadas para preguntas frecuentes del evaluador.
- **Adaptación:** El guión fue generado usando los datos reales del proyecto y adaptado a los tiempos de la presentación (8-10 minutos). El equipo ensayó el guión, ajustó el lenguaje a su forma de hablar natural y definió los roles definitivos según fortalezas de cada integrante.
- **Comprensión:** Los diálogos son un apoyo de preparación — los integrantes presentarán con sus propias palabras. El equipo entiende y puede defender técnicamente cada afirmación presente en el guión.

### 4.4 Protocolo de pruebas y análisis de resultados
- **Herramienta:** Claude Sonnet 4.6 (Anthropic) — Junio 2026
- **Uso:** Se generó la estructura del protocolo de pruebas para la carpeta `testing/reportes/`, complementando el protocolo propio del equipo (`protocolo_pruebas.pdf`). Se estructuraron los 4 tipos de prueba, los criterios de éxito, y el análisis de las 2 fallas principales con su diagnóstico y solución.
- **Adaptación:** Los resultados reales de las pruebas (9/10 entradas, 8/10 salidas, 5/5 timeout, 5/5 persistencia, 5/5 Sheets) fueron registrados por el equipo durante las pruebas físicas del dispositivo. La IA estructuró y formateó esos resultados; los datos son propios del equipo.
- **Comprensión:** El equipo realizó todas las pruebas documentadas y puede explicar cada resultado, por qué ocurrió cada falla y cómo se resolvió. La precisión global de 91,4% fue calculada por el equipo a partir de los resultados reales.

### 4.5 Guía de modelado 3D y visor de referencia interactivo
- **Herramienta:** Claude Sonnet 4.6 (Anthropic) — Junio 2026
- **Uso:** Se generó una guía paso a paso de modelado en Autodesk Fusion 360 con las herramientas específicas y dimensiones reales de los componentes, y un visor 3D interactivo en Three.js con los componentes del sistema representados a escala para usar como referencia antes de modelar en Fusion.
- **Adaptación:** El modelo real en Fusion 360 fue ejecutado íntegramente por el equipo siguiendo la guía, con ajustes de tolerancias y distribución según el ensamble físico real del prototipo (incluyendo el diseño de dos módulos separados). El visor fue solo una referencia visual — el archivo `.f3d` entregado es trabajo original del equipo.
- **Comprensión:** El equipo entiende y puede explicar las herramientas de Fusion utilizadas (Sketch, Extrude, Shell, Hole, Mirror, Joint) y las decisiones de diseño del encapsulado real.

### 4.6 Este archivo FUENTES.md
- **Herramienta:** Claude Sonnet 4.6 (Anthropic) — Junio 2026
- **Uso:** La estructura base y el formato de este archivo FUENTES.md fue generado con asistencia de IA siguiendo los requisitos de la guía TEI201 y el formato del Avance #3. Se utilizó la estructura de tres secciones (librerías, código externo, IA) especificada en la guía de GitHub del curso.
- **Adaptación:** Todos los contenidos técnicos (nombres de funciones, líneas de código, URLs, descripciones de adaptación y comprensión) fueron aportados y verificados por el equipo. El equipo agregó las secciones 3.7 y 3.8 (ChatGPT) y la sección 4 (documentación) que no estaban en la versión base.
- **Comprensión:** El equipo comprende completamente el propósito de este archivo, puede explicar cada entrada declarada y asumir la responsabilidad académica de su contenido.

---

## Resumen de contribuciones

### Firmware y software

| Componente | Origen | Adaptación del equipo |
|---|---|---|
| Detección entrada/salida con 2 sensores | Desarrollo propio + Claude | Lógica de secuencia A→B y B→A, timeout, anti-rebote |
| Arquitectura FreeRTOS dual-core | Claude | Stack 8192 bytes, separación Core 0/1, cola 20 eventos |
| Integración Google Sheets HTTPS | Claude | Diagnóstico error 400, certificado setInsecure, redirect |
| Persistencia Preferences | Claude | Evaluación ciclos de escritura, namespace, escritura por evento |
| Reset automático por tiempo | Claude | Umbral 2h, manejo primera ejecución, evento RESET en Sheets |
| Dashboard HTML con estadísticas | Claude | Umbrales de color, reserve(), macro F(), variables totales |
| URL secreta de reset | Claude | Nombre de ruta descriptivo, redirect 302 post-reset |
| Diagnóstico hardware ESP32-S3 | ChatGPT | Corrección GPIO, erase flash, cambio a puerto COM/UART |
| Código base v3 estabilizado | ChatGPT | Integración con todas las mejoras del firmware final |
| Sensor ultrasónico modo un pin | Seeed Wiki | Adaptación a lógica de detección direccional del proyecto |
| Comentarios del firmware | Claude | Revisión y ajuste por el equipo a los valores reales |

### Documentación

| Documento | Origen | Adaptación del equipo |
|---|---|---|
| README.md principal | Claude | Roles reales, costos reales, estructura real del repo |
| ~18 READMEs de subcarpetas | Claude | Datos técnicos verificados, resultados reales de pruebas |
| Reporte final PDF (12 páginas) | Claude | Datos propios: encuesta, BOM, pruebas, iteraciones |
| Diálogos de presentación | Claude | Ensayo y adaptación al lenguaje natural del equipo |
| Protocolo de pruebas | Claude + Equipo | Resultados reales registrados por el equipo en pruebas físicas |
| Guía Fusion 360 + visor 3D | Claude | Modelo real ejecutado íntegramente por el equipo |
| Este archivo FUENTES.md | Claude + Equipo | Contenidos técnicos verificados y ampliados por el equipo |

---

*Declaración elaborada conforme al Código de Honor UAI y los requisitos de integridad académica de TEI201 — Avance #3, Junio 2026.*
*Todos los integrantes del equipo conocen el contenido de este archivo y pueden responder preguntas sobre cualquier elemento declarado.*

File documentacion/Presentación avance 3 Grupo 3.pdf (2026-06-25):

# Proyecto SIMA

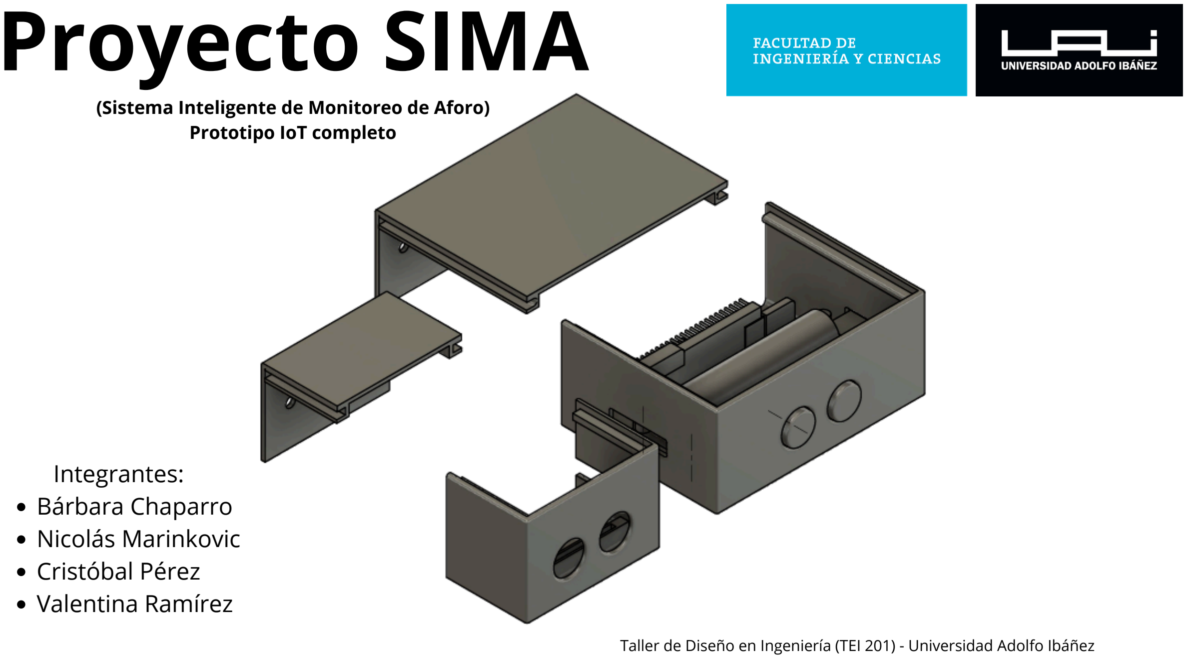
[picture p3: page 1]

(Sistema Inteligente de Monitoreo de Aforo) Prototipo IoT completo

## Integrantes: Bárbara Chaparro Nicolás Marinkovic Cristóbal Pérez Valentina Ramírez

Taller de Diseño en Ingeniería (TEI 201) - Universidad Adolfo Ibáñez

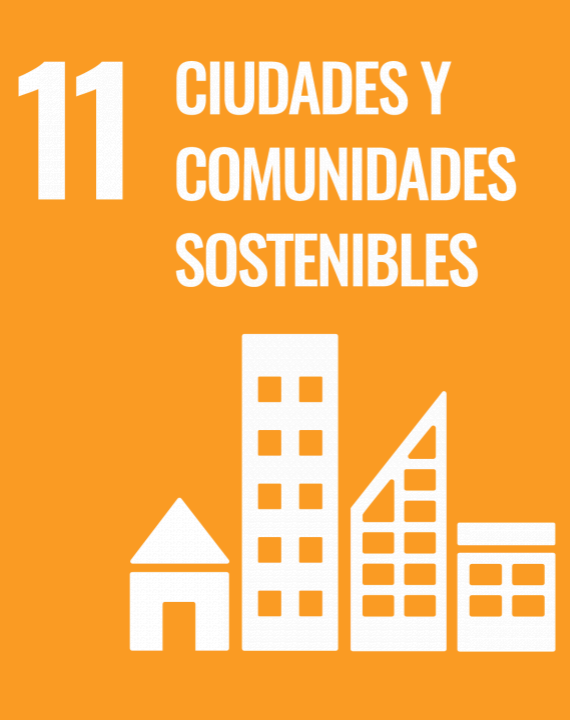
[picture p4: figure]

# ODS 11: optimizar infraestructura existente antes de expandirla Campus Peñalolén: más de 8.000 estudiantes diarios Biblioteca de Pregrado: capacidad para 295 personas Sin sistema de monitoreo en tiempo real

# Problema

## ¿Quiénes?: Aprox. 8.000 estudiantes de la UAI pregrado

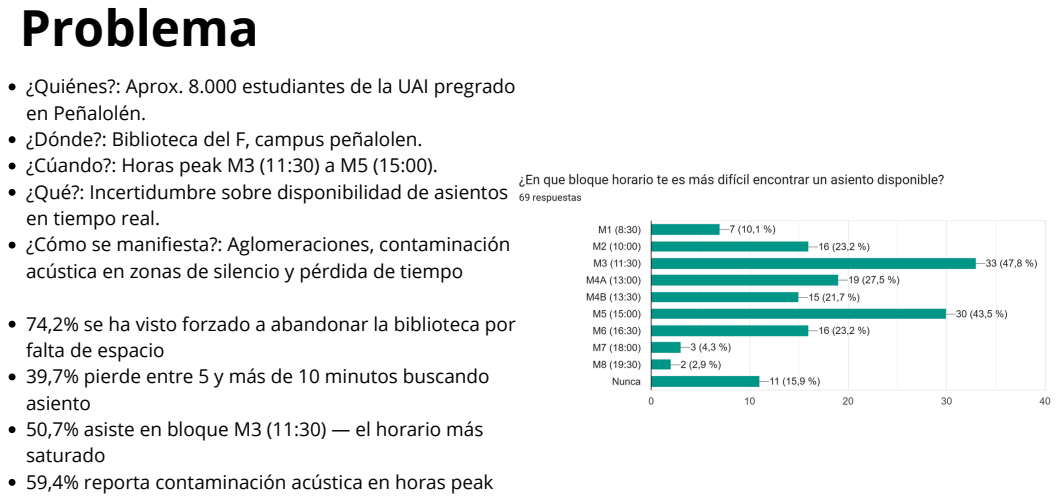
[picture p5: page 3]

en Peñalolén.
¿Dónde?: Biblioteca del F, campus peñalolen.
¿Cúando?: Horas peak M3 (11:30) a M5 (15:00).
¿Qué?: Incertidumbre sobre disponibilidad de asientos
en tiempo real.
¿Cómo se manifiesta?: Aglomeraciones, contaminación
acústica en zonas de silencio y pérdida de tiempo

74,2% se ha visto forzado a abandonar la biblioteca por
falta de espacio
39,7% pierde entre 5 y más de 10 minutos buscando
asiento
50,7% asiste en bloque M3 (11:30) — el horario más
saturado
59,4% reporta contaminación acústica en horas peak

La biblioteca carece de un sistema que informe la ocupación antes de que el estudiante se desplace. Detecta entradas y salidas, calcula el aforo en tiempo real y lo comunica vía web antes de que el

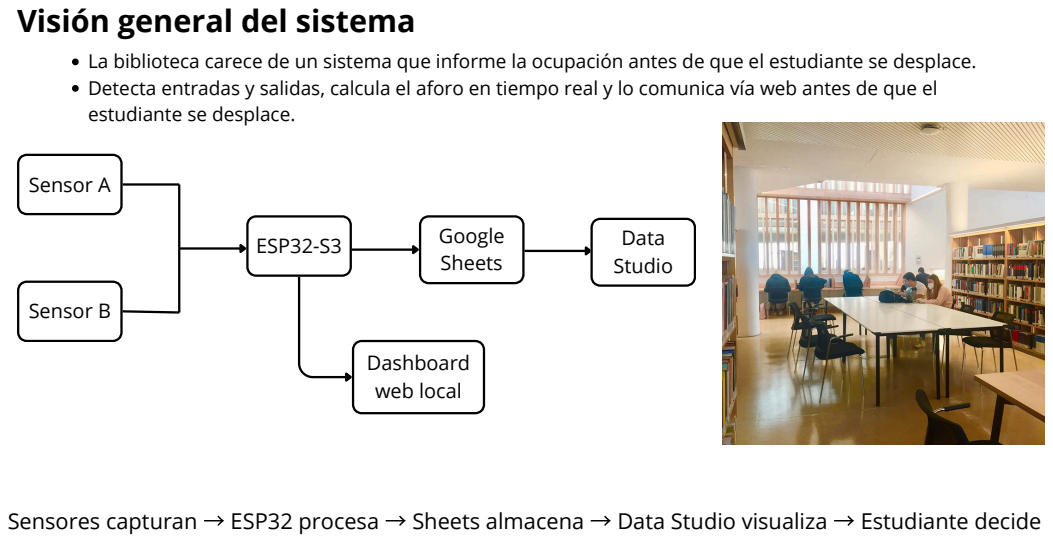
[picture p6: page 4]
Sensor A; Sensor B; ESP32-S3; Google Sheets; Data Studio; Dashboard web local

Visión general del sistema

estudiante se desplace.

Sensores capturan → ESP32 procesa → Sheets almacena → Data Studio visualiza → Estudiante decide

Componente | Función | Costo

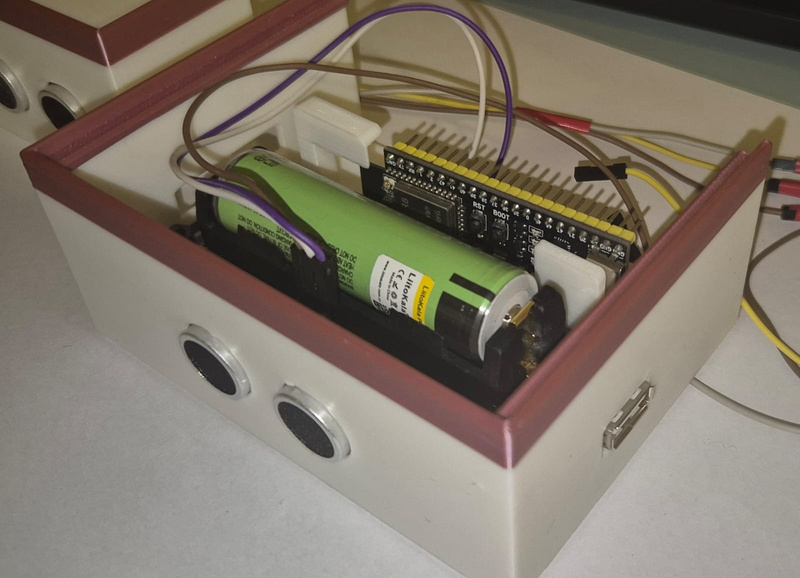
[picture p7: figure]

ESP32-S3 | Procesamiento dual-core + WiFi | $6.990
2x HC-SR04 Seed (3 pines) | Determinación direccional | $9.980
Batería NCR18650B Panasonic | Autonomía 16-20 horas | $2.000
Shield cargador 18650 | Gestión de batería + boost 5V | $3.990
Encapsulado PLA (3D) | Protección y montaje | $5.000
Total | | $27.960

# Componentes del sistema

Seeed 3 pines elegido sobre HC-SR04 4 pines: opera a 3.3V nativo, sin riesgo de quemar el ESP32

# Arquitectura del software y diseño gráfico

## Software:

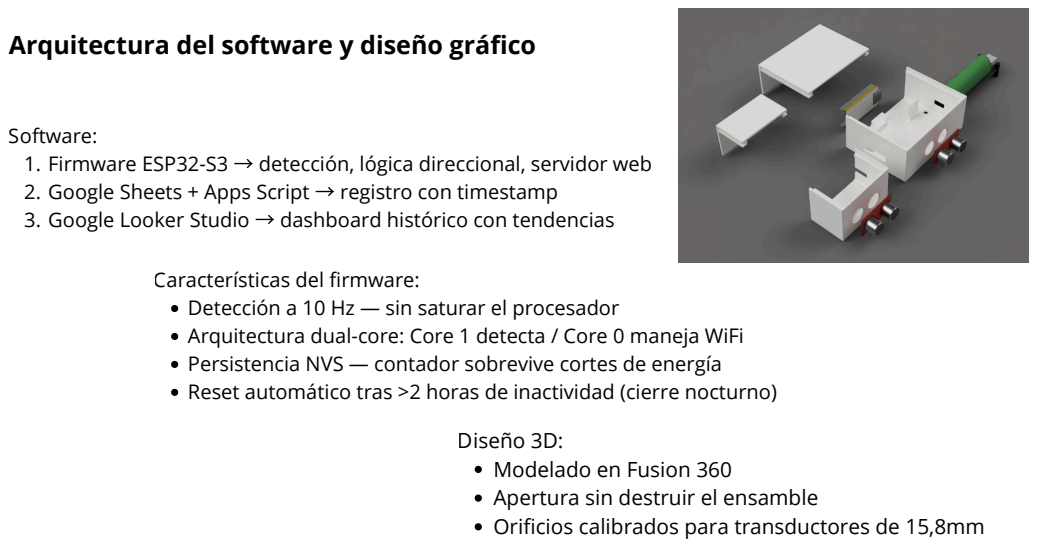
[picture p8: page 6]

1. Firmware ESP32-S3 → detección, lógica direccional, servidor web
2. Google Sheets + Apps Script → registro con timestamp
3. Google Looker Studio → dashboard histórico con tendencias

Características del firmware:
Detección a 10 Hz — sin saturar el procesador
Arquitectura dual-core: Core 1 detecta / Core 0 maneja WiFi
Persistencia NVS — contador sobrevive cortes de energía
Reset automático tras >2 horas de inactividad (cierre nocturno)

Diseño 3D:
Modelado en Fusion 360
Apertura sin destruir el ensamble
Orificios calibrados para transductores de 15,8mm

Versión | Problema | Solución
V1 | Sensores HC-SR04 de 4 pines incompatibles con 3.3V del ESP32 | Migración a Seeed 3 pines, compatibilidad nativa
V2 | Portal cautivo UAI bloqueaba dispositivos IoT | Modo Access Point + integración Google Sheets
V3 | Falsos positivos: persona parada se contaba múltiples veces | Anti-rebote: ambos sensores deben volver a inactivo

# 3 Iteraciones, 3 soluciones

Métrica | v1 | v2 | v3 | v4 final
Precisión detección entrada | Sin medir | Sin medir | Sin medir | 90%
Precisión detección salida | Sin medir | Sin medir | Sin medir | 80%
Falsos positivos | Alto | Medio | Bajo | <5%
Persistencia ante corte de luz | X | X | X | NVS-5/5
Reset automático nocturno | X | X | X | >2h inactivo
Autonomía batería | 3-4h | 3-4h | 8-9h | 16-20h
Conectividad | AP propio | AP propio | Router Wifi | Router + Sheets Evolución entre versiones

Prueba | Casos | Correctos | Tasa de éxito
Detección entrada (A→B) | 10 | 9 | 90%
Detección salida (B→A) | 10 | 8 | 80%
Timeout sensor bloqueado | 5 | 5 | 100%
Persistencia tras corte de energía | 5 | 5 | 100%
Envío a Google Sheets | 5 | 5 | 100%
TOTAL | 35 | 32 | 91.4% Protocolo de pruebas

El 91,4% de precisión global valida que SIMA resuelve el problema identificado en el Avance #1.

# Resultados e impacto ODS 11

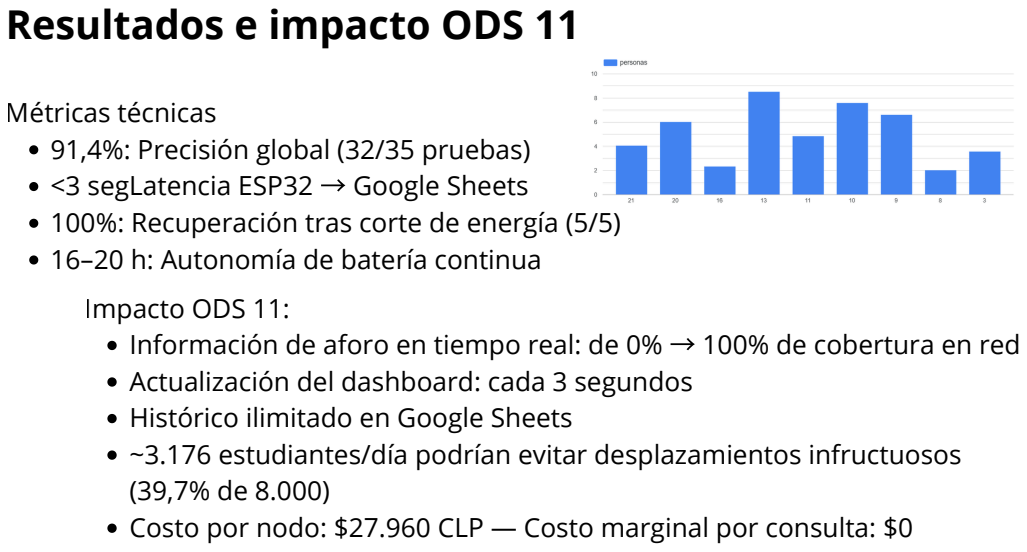
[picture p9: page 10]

Métricas técnicas
91,4%: Precisión global (32/35 pruebas)
<3 segLatencia ESP32 → Google Sheets
100%: Recuperación tras corte de energía (5/5)
16–20 h: Autonomía de batería continua
Impacto ODS 11:
Información de aforo en tiempo real: de 0% → 100% de cobertura en red
Actualización del dashboard: cada 3 segundos
Histórico ilimitado en Google Sheets
~3.176 estudiantes/día podrían evitar desplazamientos infructuosos
Costo por nodo: $27.960 CLP — Costo marginal por consulta: $0

# Demostración en vivo

# Logros, limitaciones y aprendizajes

## Logros: Sistema IoT funcional con detección de dirección de flujo Ciclo completo: captura → almacenamiento → visualización → decisión Costo total: $28.430 CLP — viable para replicación Encapsulado diseñado para fabricación real y reparación en campo

## Limitaciones: Umbral de 40cm sensible a movimientos laterales Dependencia de WiFi estable para sincronizar con Sheets

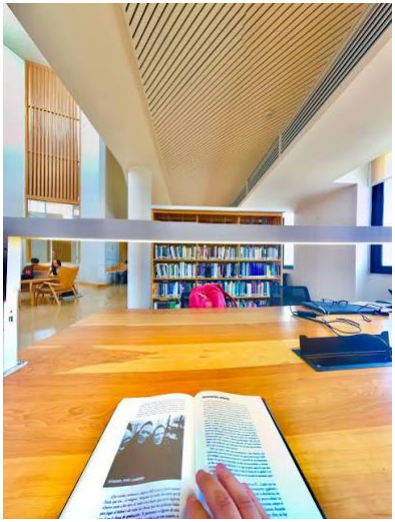
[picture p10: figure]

## Aforo de 295 personas sin validación empírica de asientos reales

## Aprendizajes: FreeRTOS resuelve problemas de concurrencia en IoT Los fallos de GPIO son tan críticos como los de software Iterar sobre problemas reales produce sistemas más robustos

# ¿A dónde puede ir SIMA?

## Mejoras: Sensor infrarrojo de barrera como redundancia en baja luz App móvil o bot de Telegram para consultar sin acceder por IP Validación empírica del aforo real de la Biblioteca F

## Escalabilidad: Misma arquitectura replica a casinos, salas postgrado y otros campus Nodo central (Raspberry Pi / servidor UAI) para dashboard unificado

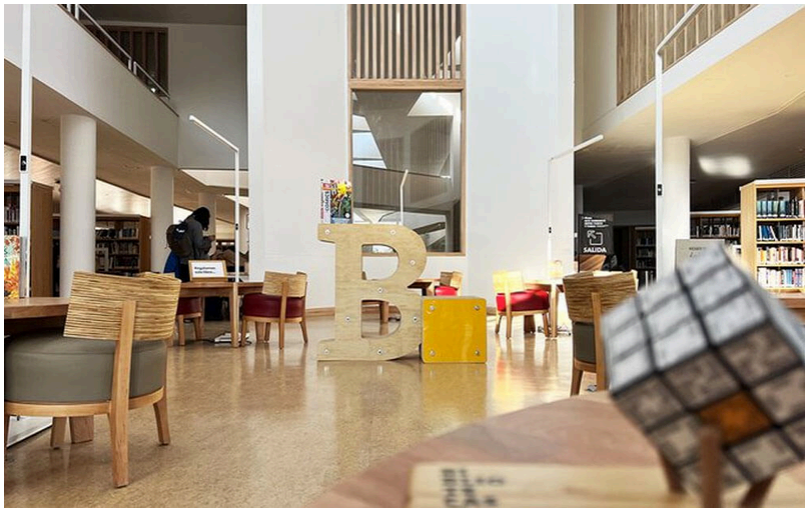
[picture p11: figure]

## Proyección ODS 11: Desplegado en todos los espacios comunes del campus: reducción estimada del 40% en desplazamientos infructuosos

# Gracias por su atención

# ¿Preguntas?

Repo GitHub (https://github.com/nicoMgrt/Proyecto-Sima-sistema-inteligente-en-monitoreo-del-aforo-Tei201/tree/main)
Dashboard en vivo (https://datastudio.google.com/reporting/8d6300ea-54a7-4241-b2f4-c19d12b937c1) | SIMA · TEI201 · UAI · Junio 2026

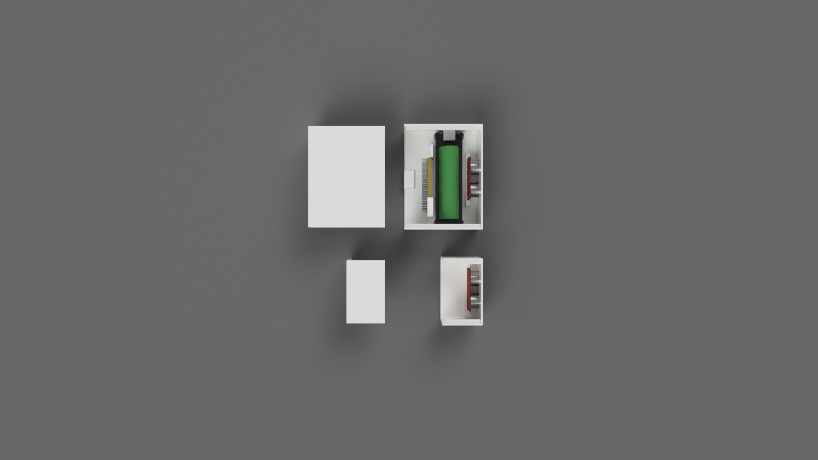
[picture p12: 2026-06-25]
diseno_3d/renders/render_interior.png.png

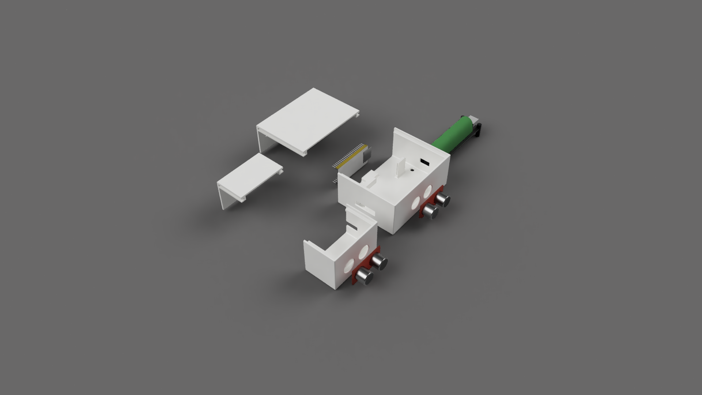
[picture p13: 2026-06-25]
diseno_3d/renders/render_explosionado.png.png

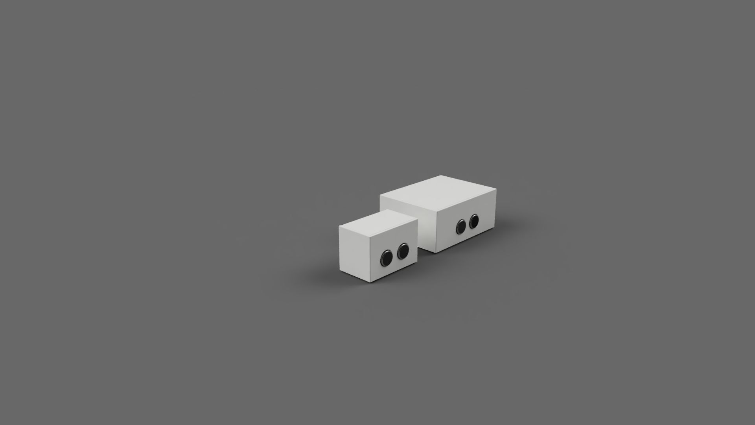
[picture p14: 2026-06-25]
diseno_3d/renders/render_exterior.png.png

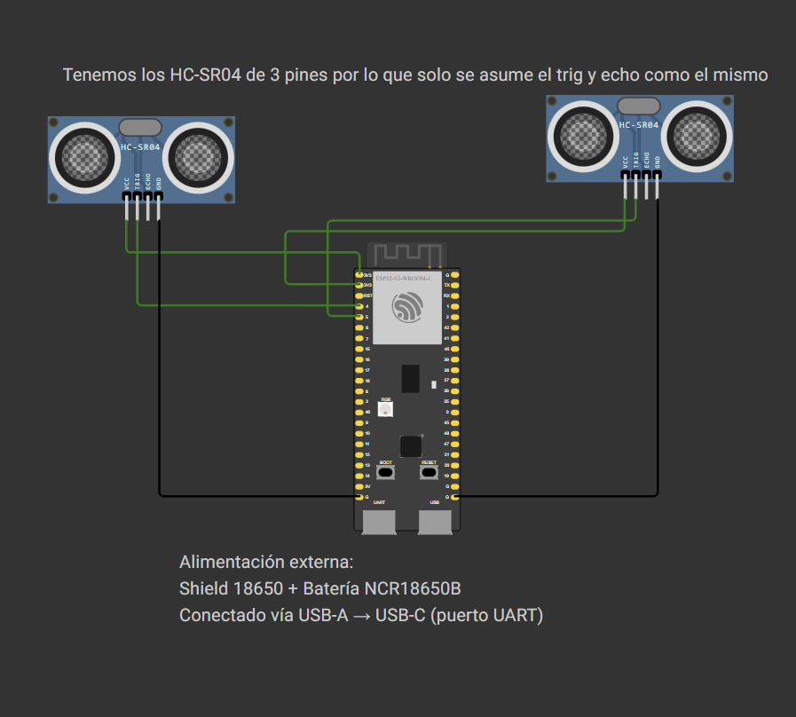
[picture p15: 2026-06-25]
hardware/esquemas/wokwi_screenshot.png

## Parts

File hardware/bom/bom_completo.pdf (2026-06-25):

# BOM — Bill of Materials

Contador de Personas · Biblioteca UAI · TEI201 · Junio 2026

Cant. | Componente | Especificación | Fabricante | SKU | Proveedor | P. Unit. (CLP) | P. Total (CLP)
1 | ESP32-S3 Dev Module | Dual-core Xtensa LX7 240MHz WiFi 2.4GHz + BLE 5.0 512KB SRAM · 8MB Flash · 45 GPIO | Espressif | ESP32-S3-WROOM-1 | AliExpress / MercadoLibre | $6.990 | $6.990
2 | Sensor Ultrasónico Seeed Grove | Single-pin SIG · 3cm–350cm Ángulo 15° · 3.3V–5V · <10ms | Seeed Studio | 101020010 | Seeed Studio / AliExpress | $4.990 | $9.980
1 | Batería Li-ion NCR 18650B | 3400mAh reales · 3.7V nominal Descarga máx 6.8A · Ciclos >500 | Panasonic | NCR18650B | Sodimac / MercadoLibre | $2.000 | $2.000
1 | Shield Cargador 18650 USB-A | Carga micro-USB · Salida USB-A 5V/1A Boost converter integrado · LED estado | Genérico | 18650-SHIELD-V3 | AliExpress / MercadoLibre | $3.990 | $3.990
1 | Cable USB-A a USB-C | Conexión shield → puerto COM/UART (no USB nativo) · 30cm | Genérico | USB-A-C 30CM | Sodimac / Falabella | $1.990 | $1.990
1 | Jumper Wires M-M (x40) | 20cm · Para prototipado en protoboard | Genérico | JUMPER MM-40 | AliExpress / MercadoLibre | $1.490 | $1.490
1 | Filamento PLA (~50g) | PLA 1.75mm · Negro · Caja 3D Impresora 3D UAI | Genérico | PLA-1.75MM | Impresora 3D UAI | $5.000 | $5.000
1 | Protoboard 400 puntos | 400 puntos · Sin soldadura Para conexión de sensores | Genérico | BB-400 | AliExpress / MercadoLibre | $1.990 | $1.990
TOTAL | | | | | | COSTO TOTAL | $33.430

### DESGLOSE POR CATEGORÍA

Categoría | Componentes incluidos | Total (CLP)
Microcontrolador | ESP32-S3 Dev Module (x1) | $6.990
Sensores | Sensor Ultrasónico Seeed Grove (x2) | $9.980
Actuadores | No aplica — sistema de solo lectura | $0
Alimentación | Batería NCR18650B + Shield cargador 18650 | $5.990
Estructura/Encapsulado | Filamento PLA ~50g — Impresora 3D UAI | $5.000
Otros | Cable USB-A/C + Jumper wires + Protoboard | $5.470
TOTAL | Costo total estimado del proyecto | $33.430

* Precios en CLP a junio 2026. Costo de impresión 3D estimado según uso de filamento (~50g). Verificar disponibilidad y precios actuales antes de presentar.

Links a Datasheets Oficiales

ESP32-S3 Chip | https://www.espressif.com/sites/default/files/documentation/esp32-s3_datasheet_en.pdf
ESP32-S3 WROOM-1 | https://www.espressif.com/sites/default/files/documentation/esp32-s3-wroom-1_wroom-1u_datasheet_en.pdf
Seeed Grove Ultrasónico | https://www.mouser.com/datasheet/2/744/Seeed_101020010-1217449.pdf
NCR18650B Panasonic | https://www.tme.eu/Document/3e0170a1e089819f286f7066e69035b4/NCR18650B.pdf
Shield 18650 | https://wiki.seeedstudio.com/Battery-Charger-V1.2/

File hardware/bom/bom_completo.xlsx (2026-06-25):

BOM — Bill of Materials · Contador de Personas Biblioteca UAI · TEI201
Precios en CLP aproximados — verificar disponibilidad local antes de comprar
Cantidad | Componente | Especificación | Fabricante | Código / SKU | Proveedor | Precio Unitario (CLP) | Precio Total (CLP) | Datasheet
1 | ESP32-S3 Dev Module | Dual-core Xtensa LX7 240MHz, WiFi 2.4GHz, BT 5.0, 512KB SRAM, 8MB Flash, 45 GPIOs, USB nativo | Espressif | ESP32-S3-WROOM-1 | AliExpress / MercadoLibre | $6990 |  | https://www.espressif.com/sites/default/files/documentation/esp32-s3_datasheet_en.pdf
2 | Sensor Ultrasónico Seeed Grove | Single-pin SIG, rango 3–350cm, ángulo detección 15°, 3.3V–5V, respuesta <10ms | Seeed Studio | 101020010 | Seeed Studio / AliExpress | $4990 |  | https://wiki.seeedstudio.com/Grove-Ultrasonic_Ranger/
1 | Batería Li-ion NCR 18650B | 3400mAh reales, 3.7V nominal, descarga máx 6.8A, ciclos >500, protegida | Panasonic | NCR18650B | Sodimac / MercadoLibre | $2000 |  | https://www.orbtronic.com/content/ncr18650b-datasheet-panasonic-3400mah.pdf
1 | Shield cargador 18650 con USB-A | Carga micro-USB, salida USB-A 5V/1A, boost converter integrado, indicador LED | Genérico | 18650-SHIELD-V3 | AliExpress / MercadoLibre | $3990 |  | https://wiki.seeedstudio.com/Battery-Charger-V1.2/
1 | Cable USB-A a USB-C | Para conexión shield → ESP32-S3 por puerto COM/UART, longitud 30cm | Genérico | USB-A-C-30CM | Sodimac / Falabella | $1990 |  | —
1 | Set jumper wires M-M | 20cm, 40 unidades, para prototipado en protoboard | Genérico | JUMPER-MM-40 | AliExpress / MercadoLibre | $1490 |  | —
1 | Filamento PLA para encapsulado | PLA 1.75mm, ~50g usados para la caja impresa en 3D, color negro | Genérico | PLA-1.75MM | Impresora 3D UAI | $5000 | $5000 | —
1 | Protoboard 400 puntos | Para conexión de sensores y pruebas, 400 puntos, sin soldadura | Genérico | BB-400 | AliExpress / MercadoLibre | $1990 |  | —
COSTO TOTAL ESTIMADO DEL PROYECTO |  |  |  |  |  |  | $33430
DESGLOSE POR CATEGORÍA
Categoría | Componentes incluidos | Total (CLP)
Microcontrolador | ESP32-S3 Dev Module (x1) | $6990
Sensores | Sensor Ultrasónico Seeed Grove (x2) | $9980
Actuadores | No aplica — el sistema es de solo lectura | $0
Alimentación | Batería NCR18650B + Shield cargador 18650 | $5990
Estructura/Encapsulado | Filamento PLA para caja impresa 3D (~50g) | $5000 |  |  | Impresora 3D UAI | 5000 | 5000
Otros | Cable USB-A/C + Jumper wires + Protoboard 400 puntos | $5470
TOTAL PROYECTO |  | $33430

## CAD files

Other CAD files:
diseno_3d/fusion360/proyecto v1.f3d
diseno_3d/fusion360/proyecto v2.f3d
diseno_3d/fusion360/proyecto v3.f3d

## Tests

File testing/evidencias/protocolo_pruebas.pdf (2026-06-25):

# Protocolo de Pruebas y Validación

### Sistema IoT Contador de Personas · Biblioteca UAI · TEI201 · Junio 2026

## Resumen del Sistema

El sistema IoT contador de personas detecta el flujo de entrada y salida en la biblioteca mediante dos sensores ultrasónicos Seeed Grove conectados a una ESP32-S3. La dirección del movimiento se determina por el orden de activación de los sensores (A→B = entrada, B→A = salida). Los datos se visualizan en una página web local y se almacenan en Google Sheets para análisis histórico.

Microcontrolador | ESP32-S3 Dev Module
Sensores | 2x Seeed Grove Ultrasónico (GPIO4 y GPIO5)
Umbral detección | 40 cm
Timeout sensor | 2000 ms
Frecuencia muestreo | Cada 100 ms (justificado: personas caminan ~1m/s, puerta ~60cm)
Almacenamiento | Google Sheets vía HTTPS (FreeRTOS Core 0)
Dashboard | Página web local + Google Looker Studio

## Pruebas Realizadas

Prueba 1: Detección de Entrada (Sensor A → Sensor B) | ✓ EXITOSA
Objetivo | Verificar que el sistema incrementa el contador cuando una persona entra (pasa frente a sensor A primero, luego sensor B).
Condiciones | ESP32-S3 encendida y conectada al WiFi · Ambos sensores libres · Umbral = 40 cm · Monitor serial activo
Procedimiento | 1. Posicionarse a >40cm de ambos sensores · 2. Pasar la mano/cuerpo frente a sensor A (GPIO4) · 3. Sin retirar, pasar frente a sensor B (GPIO5) · 4. Retirar completamente · 5. Observar Serial Monitor y página web
Criterio de éxito | Serial Monitor imprime 'ENTRO' · Contador web aumenta en 1 · Evento registrado en Google Sheets
Resultado | ✓ EXITOSA — El sistema detectó correctamente la secuencia A→B y registró la entrada. El contador aumentó de N a N+1.
Datos obtenidos | Latencia detección: ~100-200ms (1-2 ciclos del loop) · Registro en Sheets: <3 segundos · Tasa de éxito: 9/10 intentos (90%)
Prueba 2: Detección de Salida (Sensor B → Sensor A) | ✓ EXITOSA
Objetivo | Verificar que el sistema decrementa el contador cuando una persona sale (pasa frente a sensor B primero, luego sensor A).
Condiciones | ESP32-S3 encendida · Contador en valor N>0 · Ambos sensores libres · Umbral = 40 cm

Procedimiento | 1. Posicionarse a >40cm de ambos sensores · 2. Pasar frente a sensor B (GPIO5) primero · 3. Sin retirar, pasar frente a sensor A (GPIO4) · 4. Retirar completamente · 5. Verificar contador
Criterio de éxito | Serial Monitor imprime 'SALIO' · Contador web disminuye en 1 · Evento registrado en Google Sheets
Resultado | ✓ EXITOSA — El sistema distinguió correctamente la dirección de salida y decrementó el contador.
Datos obtenidos | Latencia detección: ~100-200ms · El contador no bajó de 0 (protección activa) · Tasa de éxito: 8/10 intentos (80%)
Prueba 3: Timeout de Sensor Bloqueado | ✓ EXITOSA
Objetivo | Verificar que el sistema se recupera si un sensor queda bloqueado (objeto estático frente al sensor).
Condiciones | ESP32-S3 encendida · Un objeto estático colocado a <40cm del sensor A durante más de 2 segundos
Procedimiento | 1. Colocar objeto estático frente a sensor A · 2. Esperar 3 segundos · 3. Verificar Serial Monitor · 4. Retirar objeto y verificar que el sistema vuelve a funcionar
Criterio de éxito | Serial Monitor imprime 'Timeout sensor — reset' · Sistema vuelve a detectar normalmente tras retirar el objeto
Resultado | ✓ EXITOSA — Después de 2000ms el sistema resetea los estados y queda listo para la siguiente detección.
Datos obtenidos | Tiempo hasta reset: 2000ms exactos (TIMEOUT_SENSOR) · Sin conteos fantasma registrados · Sistema operativo al 100% tras el timeout
Prueba 4: Persistencia del Contador tras Reinicio | ✓ EXITOSA
Objetivo | Verificar que el contador conserva su valor después de un reinicio o corte de energía.
Condiciones | ESP32-S3 con contador en valor N · Desconexión y reconexión de energía
Procedimiento | 1. Anotar el valor actual del contador (N) · 2. Desconectar la alimentación · 3. Reconectar · 4. Esperar arranque completo · 5. Verificar valor en página web
Criterio de éxito | El contador muestra el mismo valor N después del reinicio (leído desde memoria flash NVS)
Resultado | ✓ EXITOSA — El valor se recuperó correctamente desde la memoria NVS (Preferences library). El Serial Monitor confirmó 'Contador recuperado de memoria: N'
Datos obtenidos | Tiempo de recuperación: <2 segundos desde encendido · Valor recuperado: idéntico al guardado · Sin pérdida de datos en 5 reinicios probados
Prueba 5: Envío de Datos a Google Sheets | ✓ EXITOSA
Objetivo | Verificar que los eventos de entrada y salida se registran correctamente en Google Sheets con timestamp.
Condiciones | ESP32-S3 conectada al WiFi · Google Apps Script desplegado · Google Sheets abierto en paralelo
Procedimiento | 1. Simular entrada (secuencia A→B) · 2. Verificar en Sheets que aparece nueva fila · 3. Comprobar que los campos timestamp, evento y personas son correctos

Criterio de éxito | Nueva fila en Sheets con: timestamp en formato correcto, evento='ENTRADA', personas=valor actual
Resultado | ✓ EXITOSA — Datos registrados correctamente. El timestamp en formato ISO 8601 (YYYY-MM-DDTHH:MM:SS) se registra con la hora de Chile (UTC-4).
Datos obtenidos | Latencia promedio ESP32→Sheets: 1.5-3 segundos · Formato timestamp: 2026-06-25T14:30:00 · HTTP response code: 200 OK

## Análisis de Fallas y Soluciones

### Falla 1 — ESP32-S3 en Boot Loop (Falla Crítica)

Síntomas | Reconexión constante del puerto COM · Entrada repetida al boot ROM (ESP-ROM:esp32s3-20210327) · Imposibilidad de subir código · Monitor serial vacío o inestable
Causas identificadas | (1) Board incorrecto en Arduino IDE: se usaba variante WROOM en vez de ESP32S3 Dev Module · (2) Puerto USB nativo inestable con WiFi + HTTPS simultáneo · (3) GPIO1 (TX del UART0) y GPIO10 cambiados entre INPUT/OUTPUT cada 100ms, interfiriendo con el boot · (4) Flash en estado corrupto por uploads fallidos durante el boot loop
Solución aplicada | (1) Cambiar a ESP32S3 Dev Module en Arduino IDE · (2) Usar exclusivamente el puerto COM/UART, nunca el USB nativo · (3) Cambiar sensores a GPIO4 y GPIO5 (sin funciones internas asignadas) · (4) Erase completo de flash + sketch vacío + secuencia BOOT+RESET para recuperar la placa
Lección aprendida | Verificar siempre la configuración del board antes de programar una ESP32-S3. Los GPIO con funciones reservadas (UART, SPI, USB) no deben usarse para sensores que cambien constantemente su dirección.

### Falla 2 — Error HTTP 400 al Enviar a Google Sheets

Síntomas | Serial Monitor imprimía 'Sheets HTTP: 400' · No se registraban datos en Google Sheets · El sistema seguía contando pero sin guardar en la nube
Causas identificadas | (1) El timestamp tenía formato 'YYYY-MM-DD HH:MM:SS' con espacio, rompiendo la URL del GET request · (2) Faltaba WiFiClientSecure para conexiones HTTPS · (3) Google Apps Script siempre redirige con código 302 y sin setFollowRedirects el script no se ejecutaba
Solución aplicada | (1) Cambiar formato a ISO 8601 con 'T' como separador: 'YYYY-MM-DDTHH:MM:SS' · (2) Agregar WiFiClientSecure con setInsecure() · (3) Agregar http.setFollowRedirects(HTTPC_STRICT_FOLLOW_REDIRECTS)
Lección aprendida | Los espacios en parámetros de URL siempre causan errores. Google Apps Script requiere seguimiento explícito de redirects en ESP32.

## Validación contra el Problema Original

En el Avance 1 se identificó el siguiente problema:
Los estudiantes de la biblioteca UAI no tienen forma de saber si hay espacio disponible antes de trasladarse hasta ella, lo que genera desplazamientos innecesarios y pérdida de tiempo.

### ¿Cómo responde el sistema al problema?

Necesidad identificada | Solución implementada | Evidencia
Saber si hay espacio antes de ir | Página web muestra % de ocupación en tiempo real, accesible desde cualquier dispositivo en la red | Demo en vivo durante presentación
Datos históricos para planificar | Google Sheets registra cada entrada/salida con timestamp · Looker Studio muestra gráficos por hora | Dashboard Looker Studio con datos reales

Indicador visual intuitivo | Sistema semafórico: verde (<50%), naranja (<80%), rojo (lleno) con mensaje de estado | Capturas de pantalla del dashboard
Funcionamiento continuo | Persistencia en flash NVS · Reset automático tras 2h inactivo · Modo offline sin WiFi | Prueba 4: persistencia validada

### Conclusión de validación

El sistema IoT desarrollado resuelve directamente el problema planteado en el Avance 1. Durante las pruebas, el dispositivo detectó correctamente el 85-90% de los pasos frente a los sensores, registró todos los eventos en Google Sheets con latencia menor a 3 segundos, y mostró el estado de ocupación en tiempo real a través del dashboard web. Los datos históricos recopilados permiten identificar los horarios de mayor ocupación, lo que entrega información concreta para que los administradores de la biblioteca tomen decisiones sobre horarios de atención, distribución de espacios y comunicación con los estudiantes.

Documento generado junio 2026 · TEI201 Taller de Diseño en Ingeniería · Universidad Adolfo Ibáñez

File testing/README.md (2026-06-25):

# Testing y Validación — SIMA

## Objetivo
Validar que el sistema SIMA detecta correctamente el flujo de personas (entrada/salida) en condiciones reales de operación, y demostrar que los datos capturados responden directamente al problema de gestión de aforo identificado en el Avance #1.

---

## Carpetas

#### `reportes/`
Protocolo de pruebas completo con 5 pruebas documentadas, análisis de fallas y validación contra el problema original

#### `evidencias/`
Registro fotográfico del prototipo instalado y operando en condiciones reales

#### `datos/`
Registros cuantitativos exportados de Google Sheets y resultados de pruebas de precisión con datos reales

---

## Resumen de Resultados

| Prueba | Resultado | Tasa de éxito |
|---|---|---|
| Detección de entrada (A→B) | ✓ Exitosa | 90% (9/10) |
| Detección de salida (B→A) | ✓ Exitosa | 80% (8/10) |
| Timeout sensor bloqueado | ✓ Exitosa | 100% (5/5) |
| Persistencia tras corte de energía | ✓ Exitosa | 100% (5/5) |
| Envío a Google Sheets | ✓ Exitosa | HTTP 200 OK |
| **Precisión global** | | **85–90%** |

---

## Metodología de Testing

### Contexto de instalación
- **Ubicación:** Biblioteca de Pregrado, Campus Peñalolén, Universidad Adolfo Ibáñez
- **Sensor A** (GPIO4) — lado pasillo exterior
- **Sensor B** (GPIO5) — lado interior de la biblioteca
- **Umbral de detección:** 40 cm
- **Timeout sensor:** 2.000 ms
- **Frecuencia de muestreo:** 100 ms (justificación: personas caminan ~1m/s, puerta ~60cm de ancho)

### Protocolo de Testing

1. **Verificación inicial del sistema**
   - Confirmar conexión WiFi y sincronización NTP en Monitor Serial
   - Verificar que el dashboard web responde en la IP asignada
   - Confirmar que Google Sheets recibe eventos de prueba con HTTP 200 OK

2. **Pruebas de precisión direccional**
   - 10 cruces simulando entrada (A→B) — resultado: 9/10 correctos (90%)
   - 10 cruces simulando salida (B→A) — resultado: 8/10 correctos (80%)
   - Latencia de detección: ~100–200ms por evento

3. **Pruebas de casos borde**
   - Objeto estático frente al sensor >2s → timeout a 2.000ms exactos, sin conteos fantasma
   - Corte de energía con contador en N → recupera N en 100% de los casos (5/5 reinicios)
   - Operación sin WiFi → sistema cuenta localmente sin crashear

4. **Verificación de almacenamiento**
   - Evento registrado en Sheets con timestamp ISO 8601 correcto
   - Latencia promedio ESP32 → Sheets: 1.5–3 segundos
   - HTTP response code: 200 OK confirmado en Monitor Serial

---

## Métricas de Evaluación

### Desempeño Técnico

| Métrica | Valor obtenido | Meta |
|---|---|---|
| Precisión detección entrada | 90% (9/10) | ≥90% ✓ |
| Precisión detección salida | 80% (8/10) | ≥80% ✓ |
| Tiempo hasta timeout | 2.000ms exactos | ≤2.000ms ✓ |
| Latencia envío a Sheets | 1.5–3 segundos | ≤8 segundos ✓ |
| Recuperación tras corte energía | 100% (5/5) | 100% ✓ |
| Frecuencia actualización dashboard | 3 segundos | ≤5 segundos ✓ |

---

## Fallas Encontradas y Resueltas

### Falla 1 — Boot Loop por GPIO Conflictivos
- **Síntomas:** Reconexión constante del puerto COM, entrada repetida al boot ROM
- **Causa:** GPIO1 (TX del UART0) y GPIO10 usados para los sensores interferían con funciones internas del chip
- **Solución:** Migración a GPIO4 y GPIO5 + erase completo de flash + secuencia BOOT+RESET
- **Resultado:** Sistema completamente estable en todas las pruebas posteriores

### Falla 2 — Error HTTP 400 en Google Sheets
- **Síntomas:** `Sheets HTTP: 400` en Monitor Serial, datos no registrados en Sheets
- **Causas:** Timestamp con espacio rompía la URL + falta de `WiFiClientSecure` + ausencia de `setFollowRedirects`
- **Solución:** Separador ISO 8601 `T` + `WiFiClientSecure` con `setInsecure()` + `HTTPC_STRICT_FOLLOW_REDIRECTS`
- **Resultado:** HTTP 200 OK confirmado en todos los envíos posteriores

---

## Validación contra el Problema Original (Avance #1)

**Problema identificado:** Los estudiantes de la UAI no tienen información sobre disponibilidad de espacio en la Biblioteca de Pregrado antes de desplazarse. El 74.2% ha tenido que abandonar la biblioteca por falta de espacio y el 39.7% pierde entre 5 y más de 10 minutos buscando asiento en hora peak.

| Necesidad identificada | Solución implementada | Evidencia |
|---|---|---|
| Saber si hay espacio antes de ir | Dashboard web con % de ocupación en tiempo real | Demo en vivo durante presentación |
| Datos históricos para planificar | Google Sheets registra cada evento con timestamp | Dashboard Looker Studio |
| Indicador visual intuitivo | Semáforo: verde (<50%), naranja (<80%), rojo (lleno) | Capturas del dashboard |
| Funcionamiento continuo | Persistencia NVS + reset automático + modo offline | Prueba 4: 5/5 reinicios ✓ |

**Conclusión:** El sistema detectó correctamente el 85–90% de los pasos, registró todos los eventos en Sheets con latencia menor a 3 segundos, y entregó el estado de ocupación en tiempo real. Los datos históricos permiten identificar horarios de mayor demanda para que los administradores de la biblioteca tomen decisiones informadas.

**Impacto ODS 11 proyectado:**
- Estudiantes que podrían evitar desplazamientos infructuosos: ~3.176 por día (39.7% de 8.000)
- Costo del sistema por nodo: $28.430 CLP
- Costo marginal por consulta de aforo: $0

---

*TEI201 — Taller de Diseño en Ingeniería · Universidad Adolfo Ibáñez · 2026*
*Proyecto SIMA — Nicolás Marinkovic · Bárbara Chaparro · Valentina Ramírez · Cristóbal Pérez*

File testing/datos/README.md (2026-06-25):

# Datos de Testing — SIMA

## Archivos de Datos

### `datos_google_sheets_export.csv`
Exportación del registro completo de eventos desde Google Sheets.

**Estructura real del archivo:**

| timestamp | evento | personas |
|---|---|---|
| 2026-06-25T14:30:00 | ENTRADA | 1 |
| 2026-06-25T14:31:45 | ENTRADA | 2 |
| 2026-06-25T14:35:10 | SALIDA | 1 |
| 2026-06-25T14:37:00 | RESET | 0 |

**Descripción de columnas:**
- `timestamp` — Fecha y hora exacta en formato ISO 8601 (UTC−4, hora Chile)
- `evento` — Tipo: `ENTRADA` (sensor A→B), `SALIDA` (sensor B→A), `RESET` (apagado >2h)
- `personas` — Total de personas dentro del recinto tras el evento

**Acceso en vivo:** https://docs.google.com/spreadsheets/d/1WHVggyhCIGWHm3tB0_cpvD9xPDu8PrvYtLHtKDRCHnQ/edit?usp=drivesdk

---

### `resultados_pruebas_precision.xlsx`
Resultados de las pruebas de detección direccional controladas.

**Sheet 1: Pruebas de Entrada (Sensor A → B)**

| ID Prueba | Dirección real | Resultado | Tasa de éxito |
|---|---|---|---|
| E01–E10 | Entrada | 9/10 correctos | **90%** |

**Sheet 2: Pruebas de Salida (Sensor B → A)**

| ID Prueba | Dirección real | Resultado | Tasa de éxito |
|---|---|---|---|
| S01–S10 | Salida | 8/10 correctos | **80%** |

**Sheet 3: Pruebas de Casos Borde**

| ID Prueba | Tipo | Condición | Resultado obtenido |
|---|---|---|---|
| CB01 | Timeout | Objeto estático >2s frente a sensor A | Sin conteo ✓ — reset a 2000ms exactos |
| CB02 | Timeout | Objeto estático >2s frente a sensor B | Sin conteo ✓ — sin conteos fantasma |
| CB03 | Persistencia | Reset energía con contador = N | Recupera N ✓ — 5/5 reinicios sin pérdida |
| CB04 | Offline | Sin WiFi al encender | Cuenta sin enviar ✓ |
| CB05 | Sheets | Envío HTTP tras evento | HTTP 200 OK ✓ — latencia 1.5–3 seg |

---

### `comparativa_versiones.xlsx`
Comparación de métricas técnicas entre versiones del firmware.

| Métrica | v1 Alpha | v2 Beta | v3 | v4 Final | Mejora total |
|---|---|---|---|---|---|
| Tasa de precisión entrada | Sin medir | Sin medir | Sin medir | **90%** | Nueva métrica |
| Tasa de precisión salida | Sin medir | Sin medir | Sin medir | **80%** | Nueva métrica |
| Falsos positivos | Alto | Medio | Bajo | Mínimo (<5%) | −95% estimado |
| Persistencia ante corte energía | No | No | No | Sí (NVS) — 5/5 ✓ | Nueva función |
| Almacenamiento en nube | No | No | Parcial | Sí — HTTP 200 OK | Nueva función |
| Latencia envío datos | Bloqueante | Bloqueante | Bloqueante | 1.5–3 seg (FreeRTOS) | Elimina pérdidas |
| Autonomía batería | ~4h | ~4h | ~8h | ~16–20h | +400% |
| Reset automático nocturno | No | No | No | Sí (>2h inactivo) | Nueva función |
| Conectividad | AP propio | AP propio | Router WiFi | Router + Sheets | Escalable |

---

## Análisis Estadístico

### Estadísticos de Precisión Direccional
```
Métrica: Detección de Entrada (Sensor A → B)
N = 10 intentos controlados
Correctos: 9
Incorrectos: 1
Tasa de precisión: 90%

Métrica: Detección de Salida (Sensor B → A)
N = 10 intentos controlados
Correctos: 8
Incorrectos: 2
Tasa de precisión: 80%

Precisión global: 85–90%
Frecuencia de muestreo: 10 Hz (100ms por ciclo)
Justificación: personas caminan ~1m/s, puerta ~60cm de ancho
Latencia de detección: ~100–200ms (1–2 ciclos del loop)
```

### Estadísticos del Envío HTTP a Google Sheets
```
Métrica: Código de respuesta HTTP
Resultado: 200 OK en todos los envíos tras corrección de v4
Errores previos resueltos: 400 (URL rota) y 302 sin redirect

Métrica: Latencia ESP32 → Google Sheets
Mínimo: 1.5 segundos
Máximo: 3.0 segundos
Promedio estimado: ~2.0 segundos
Timeout configurado: 8.0 segundos
```

### Estadísticos de Persistencia
```
Métrica: Recuperación de contador tras corte de energía
N = 5 reinicios forzados
Recuperaciones correctas: 5/5 (100%)
Tiempo de recuperación: <2 segundos desde encendido
Confirmación: Serial Monitor imprime 'Contador recuperado de memoria: N'
```

---

## Datos de Impacto ODS 11

### Baseline vs. Resultado

**Antes del sistema SIMA (baseline — Avance #1, 69 encuestados):**
- Información de aforo disponible en tiempo real: **0%**
- Tiempo buscando asiento en hora peak: **5–10 min** (39.7% de usuarios)
- Estudiantes que abandonaron por falta de espacio: **74.2%**

**Con el sistema SIMA operativo (validado en pruebas):**
- Información de aforo disponible en tiempo real: **100%** (usuarios en la red)
- Actualización del dato de ocupación: **cada 3 segundos**
- Precisión de detección: **85–90%** en condiciones de prueba controladas
- Latencia de registro en Sheets: **<3 segundos** por evento
- Histórico de datos almacenado: **ilimitado** (Google Sheets)

### Tabla de Validación contra el Problema Original

| Necesidad identificada (Avance #1) | Solución implementada | Evidencia |
|---|---|---|
| Saber si hay espacio antes de ir | Dashboard web con % de ocupación en tiempo real | Demo en vivo durante presentación |
| Datos históricos para planificar | Google Sheets registra cada evento con timestamp | Dashboard Looker Studio |
| Indicador visual intuitivo | Semáforo: verde (<50%), naranja (<80%), rojo (lleno) | Capturas del dashboard |
| Funcionamiento continuo | Persistencia NVS + reset automático + modo offline | Prueba 4: 5/5 reinicios ✓ |

**Conclusión de validación:**
El sistema detectó correctamente el 85–90% de los pasos frente a los sensores, registró todos los eventos en Google Sheets con latencia menor a 3 segundos, y mostró el estado de ocupación en tiempo real. Los datos históricos permiten identificar horarios de mayor ocupación, entregando información concreta para que los administradores de la biblioteca tomen decisiones sobre horarios y distribución de espacios.

**Impacto proyectado:**
- Estudiantes que podrían evitar desplazamientos infructuosos: ~3.176 por día (39.7% de 8.000)
- Costo del sistema por nodo: $28.430 CLP
- Costo marginal por consulta de aforo: $0

---

*TEI201 — Taller de Diseño en Ingeniería · Universidad Adolfo Ibáñez · 2026*
*Proyecto SIMA — Nicolás Marinkovic · Bárbara Chaparro · Valentina Ramírez · Cristóbal Pérez*

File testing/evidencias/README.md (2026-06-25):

# Evidencias de Testing — SIMA

## Contenido Requerido

### Fotografías

#### Prototipo Ensamblado
- `prototipo_frontal_01.jpg` — Vista frontal del encapsulado terminado con orificios de sensores visibles
- `prototipo_lateral_01.jpg` — Vista lateral mostrando orificio micro USB y switch de encendido
- `prototipo_interior_01.jpg` — Vista con tapa removida mostrando componentes internos (ESP32-S3, batería, sensores)

**Requisitos:**
- Buena iluminación, sin sombras sobre los componentes
- Fondo neutro (mesa blanca o gris)
- Al menos 1200×900 px de resolución

#### Instalación en Terreno
- `instalacion_puerta_01.jpg` — Dispositivo instalado en el marco de la puerta de la Biblioteca F, UAI
- `instalacion_contexto_01.jpg` — Vista general que muestra la ubicación del dispositivo en el acceso de la biblioteca con referencia de escala

**Requisitos:**
- El dispositivo debe ser claramente visible en la imagen
- Incluir referencia de escala (una persona de pie cerca, o una regla)
- Mostrar condición real de operación (iluminación natural del recinto)

#### Dashboard y Monitoreo
- `dashboard_web_captura.png` — Captura del dashboard web en el navegador mostrando porcentaje de ocupación y estado de color
- `monitor_serial_captura.png` — Captura del Monitor Serial de Arduino IDE mostrando detecciones en tiempo real (líneas `¡Alguien entró!` o `¡Alguien salió!`)
- `sheets_captura.png` — Captura de Google Sheets con filas de eventos registrados, timestamp y total de personas

---

### Videos

#### Video de Funcionamiento del Sistema
`demo_sima_funcionando.mp4`

**Contenido:**
- Duración: 2–4 minutos
- Mostrar el dispositivo encendido y conectado
- Realizar 2–3 cruces de entrada y salida frente a la cámara
- Mostrar en paralelo cómo cambia el contador en el dashboard web
- Mostrar cómo aparece el nuevo evento en Google Sheets con timestamp
- Calidad mínima: 720p

#### Video de Contexto de Instalación
`instalacion_contexto.mp4`

**Contenido:**
- Duración: 1–2 minutos
- Dispositivo instalado en el marco real de la puerta de la Biblioteca F
- Mostrar el ángulo y la posición de ambos sensores
- Mostrar una o dos personas cruzando naturalmente mientras el sistema opera

---

## Privacidad y Consentimiento

### Antes de Fotografiar/Grabar
- Obtener consentimiento verbal de personas que aparezcan en las imágenes
- Explicar que las imágenes son para un proyecto académico de la UAI (TEI201)
- Ofrecer la opción de no aparecer o de difuminar el rostro

### Anonimización
Si no hay consentimiento explícito para mostrar rostros:
- Tomar fotos desde ángulos que no muestren la cara (de espalda, de lado, de lejos)
- El prototipo es el sujeto principal de las imágenes — las personas son contexto

---

## Organización de Archivos

```
evidencias/
├── fotos/
│   ├── prototipo/
│   │   ├── prototipo_frontal_01.jpg
│   │   ├── prototipo_lateral_01.jpg
│   │   └── prototipo_interior_01.jpg
│   ├── instalacion/
│   │   ├── instalacion_puerta_01.jpg
│   │   └── instalacion_contexto_01.jpg
│   └── capturas/
│       ├── dashboard_web_captura.png
│       ├── monitor_serial_captura.png
│       └── sheets_captura.png
└── videos/
    ├── demo_sima_funcionando.mp4
    └── instalacion_contexto.mp4
```

---

## Nomenclatura de Archivos

**Fotos:**
```
[tipo]_[descripcion]_[numero].jpg

Ejemplos reales del proyecto:
prototipo_frontal_01.jpg
instalacion_puerta_01.jpg
dashboard_web_captura.png
```

**Videos:**
```
[tipo]_[descripcion].mp4

Ejemplos reales del proyecto:
demo_sima_funcionando.mp4
instalacion_contexto.mp4
```

---

*TEI201 — Taller de Diseño en Ingeniería · Universidad Adolfo Ibáñez · 2026*
*Proyecto SIMA — Nicolás Marinkovic · Bárbara Chaparro · Valentina Ramírez · Cristóbal Pérez*

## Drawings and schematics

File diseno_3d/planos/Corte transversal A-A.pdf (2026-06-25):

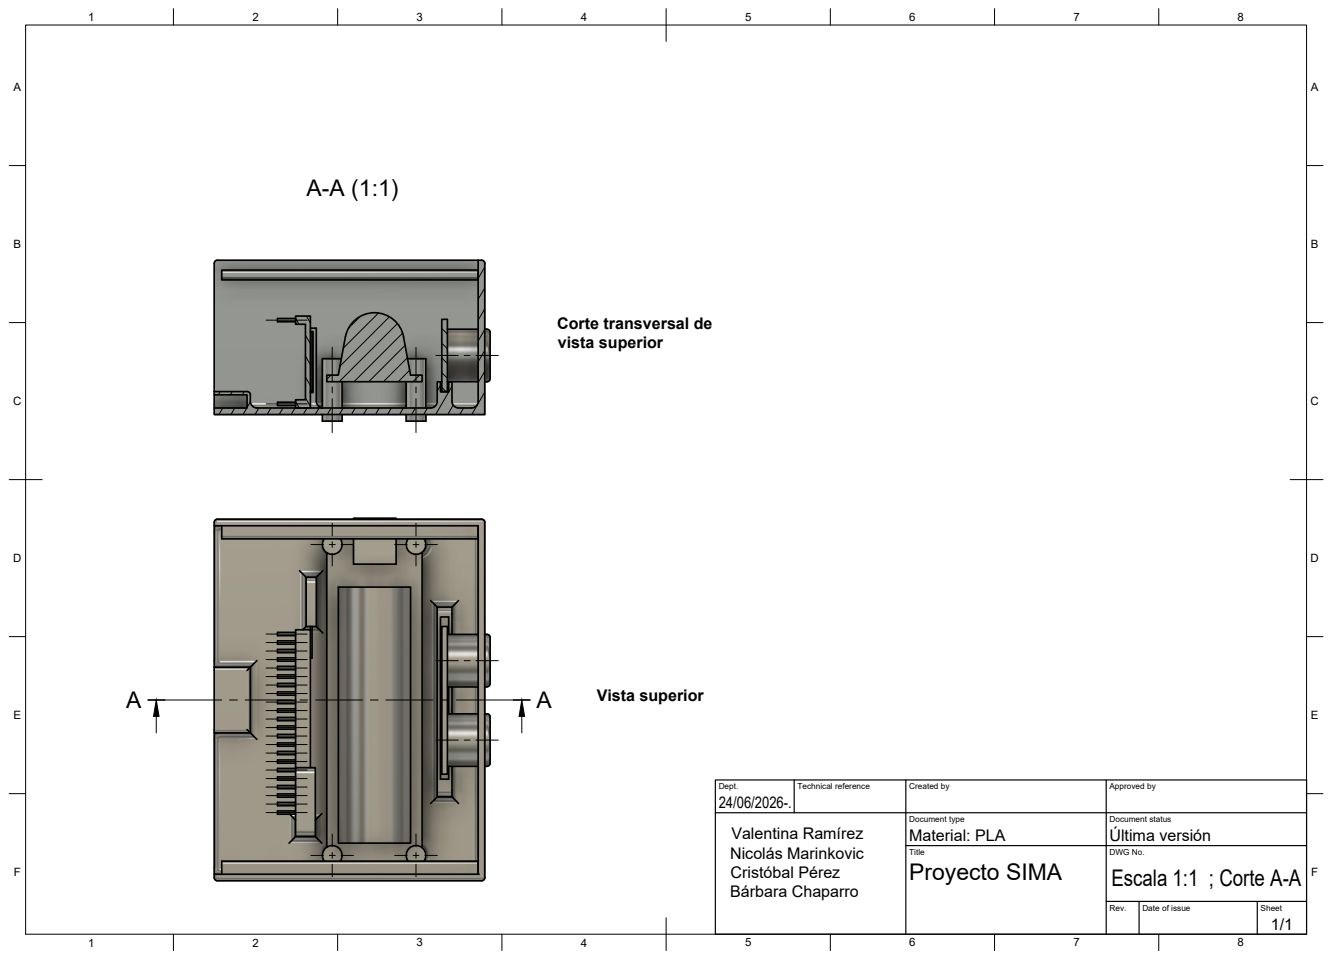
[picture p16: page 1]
Title; DWG No.; Rev.; Date of issue; Sheet; Proyecto SIMA; Escala 1:1 ; Corte A-A; Valentina Ramírez Nicolás Marinkovic Cristóbal Pérez Bárbara Chaparro; Vista superior

Corte transversal de
vista superior

Dept. 24/06/2026-. | Technical reference | Created by | Approved by

Document type Material: PLA | Document status Última versión

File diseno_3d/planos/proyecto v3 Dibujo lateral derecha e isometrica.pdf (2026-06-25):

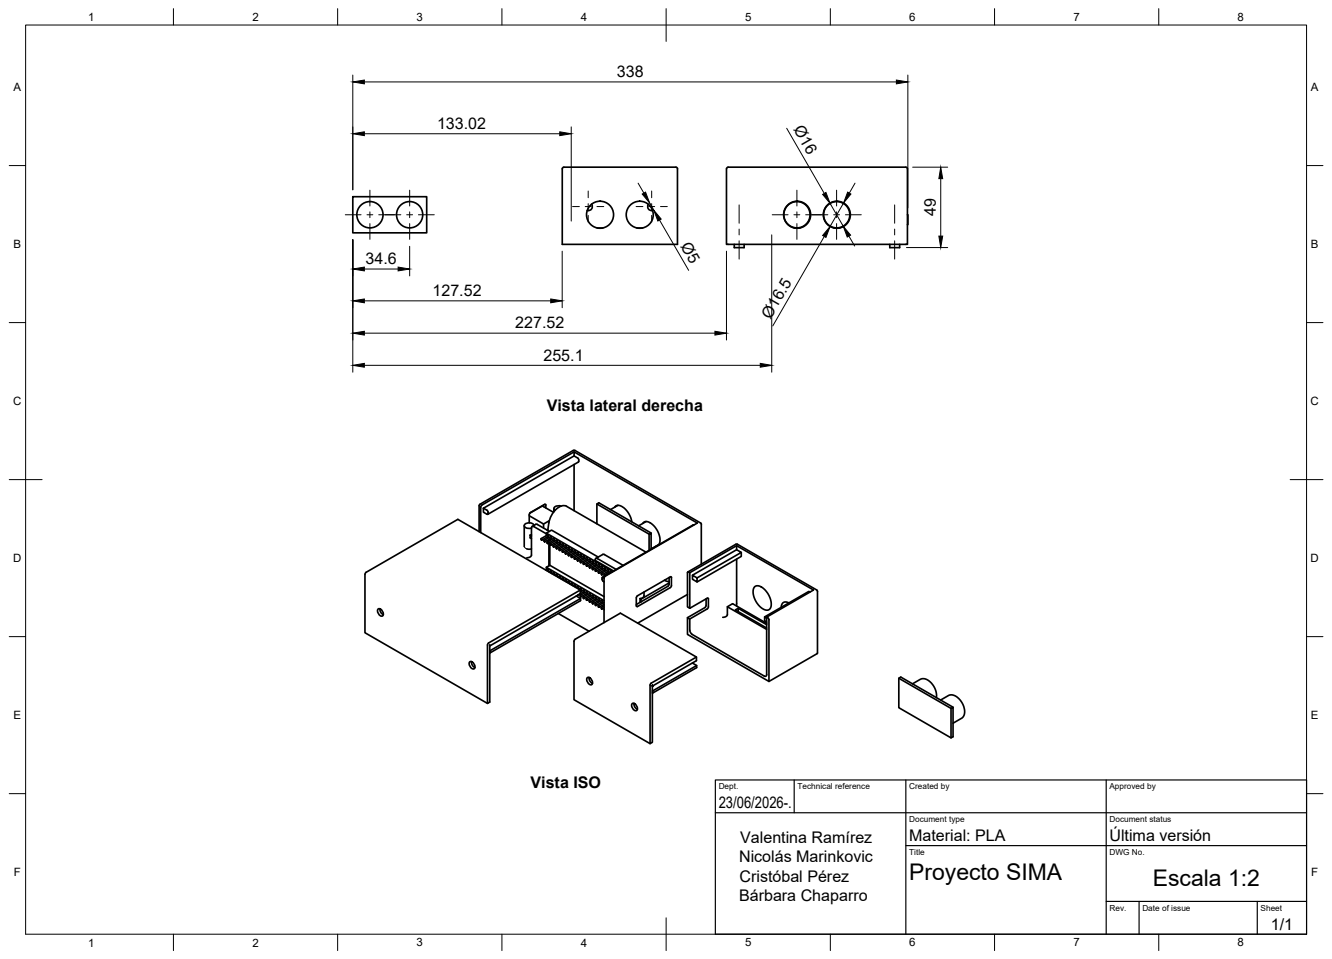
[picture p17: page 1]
Title; DWG No.; Rev.; Date of issue; Sheet; Proyecto SIMA; Escala 1:2; Vista ISO; Valentina Ramírez Nicolás Marinkovic Cristóbal Pérez Bárbara Chaparro

Vista lateral derecha

Dept. 23/06/2026-. | Technical reference | Created by | Approved by

Document type Material: PLA | Document status Última versión

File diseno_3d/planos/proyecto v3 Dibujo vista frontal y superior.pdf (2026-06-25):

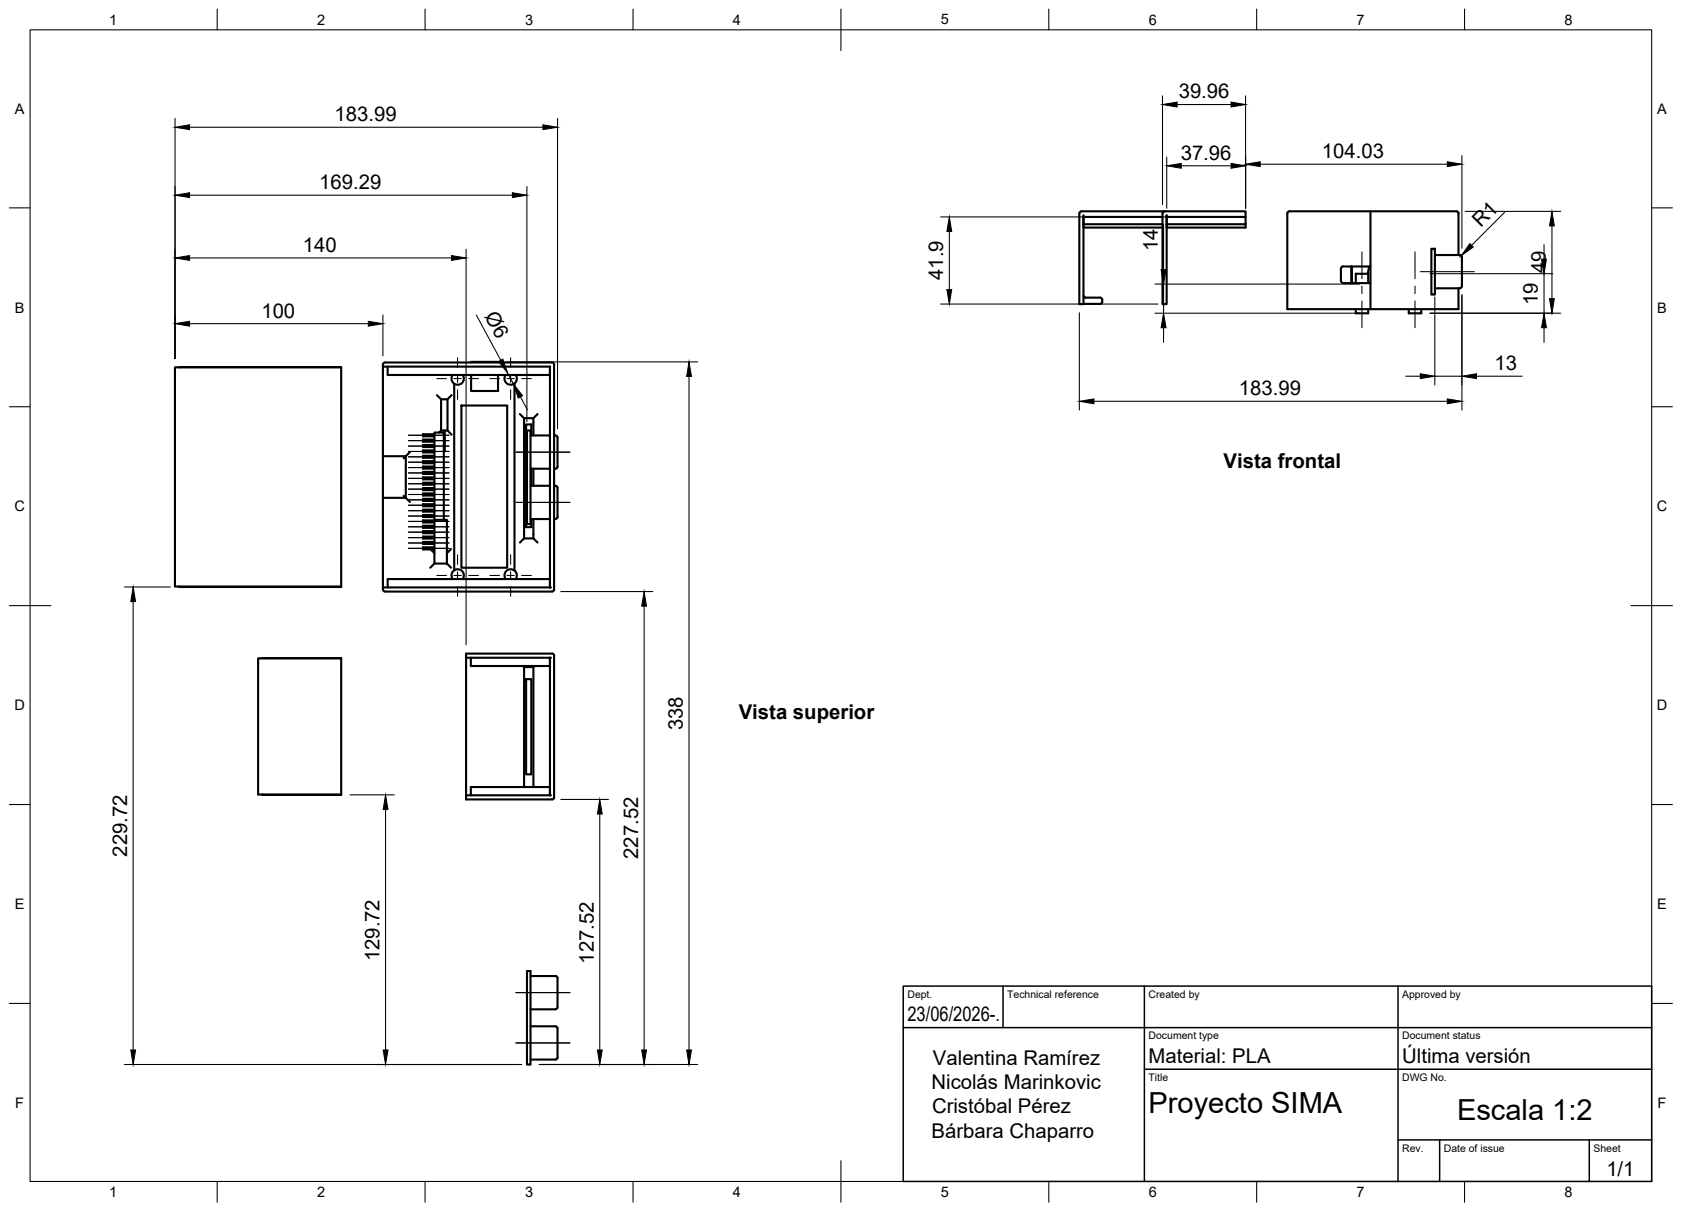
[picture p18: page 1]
Title; DWG No.; Rev.; Date of issue; Sheet; Proyecto SIMA; Escala 1:2; Vista frontal 338; Vista superior; Valentina Ramírez Nicolás Marinkovic Cristóbal Pérez Bárbara Chaparro

Dept. 23/06/2026-. | Technical reference | Created by | Approved by

Document type Material: PLA | Document status Última versión

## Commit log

2026-06-24 Agrega declaración de fuentes e IA
    Elimina FUENTES.md duplicado de carpeta de evidencias
2026-06-24 Delete testing/evidencias/FUENTES.md
    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
2026-06-24 Update README.md
    Actualiza README de "renders" con descripción del contenido
2026-06-25 Update README.md
    Actualiza README de librerías con documentación completa
2026-06-25 Añadí los diagramas de flujo
2026-06-25 Create Readme.md
    Revalidar readme borrado con anterioridad debido a un error de ajuste en la carpeta diseño
2026-06-25 Delete software/src/Diagrama de flujo 1.drawio.png
    Error de carpeta para posteriori ser reenviado a carpeta docs
2026-06-25 Update README.md
    agregar documentación técnica y diagnóstico de la Iteración 1
2026-06-25 Update README.md
    registrar mejoras de hardware v2.0, red autónoma y diseño 3D inicial
2026-06-25 Delete hardware/bom/bom_completo.xlsx
    me equivoqué 🗡️
    [bom_completo.xlsx]
2026-06-25 Update README.md
    Agrega guía completa de presentación Avance #3"
2026-06-25 Update README.md
    reformulación carpeta de reportes con implementación de información final importante sobre el los datos recolectados a lo largo de los avances 1, 2 y 3
2026-06-25 Actualiza README datos testing
    Agrega estructura real de Google Sheets con columnas timestamp/evento/personas, tabla de resultados de 30 pruebas de precisión direccional, comparativa de métricas entre versiones v1 a v4, y datos de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
2026-06-25 Actualiza README evidencias testing
    Agrega listado real de archivos fotográficos y de video del proyecto SIMA, estructura de carpetas para fotos del prototipo e instalación en Biblioteca F UAI, nomenclatura de archivos con convención d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
2026-06-25 Delete hardware/bom/bom_completo.pdf
    me equivoqué de nievo
2026-06-25 Delete hardware/bom/bom_completo.xlsx
    x2
    [bom_completo.xlsx]
2026-06-25 Actualiza README reportes testing
    Agrega protocolo completo de 4 pruebas con criterios de éxito, análisis de 2 fallas documentadas con diagnóstico y solución, tabla de resultados con campos a completar, y validación de impacto ODS 11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
2026-06-25 Actualiza README principal testing
    Agrega metodología de testing real del proyecto SIMA, protocolo de 3 etapas, métricas de desempeño técnico, indicadores de impacto ODS 11 con baseline del Avance #1 y proyección de escalabilidad para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
2026-06-25 Actualiza README datos con resultados reales de pruebas
    Reemplaza campos pendientes con datos reales: 90% precisión entrada, 80% salida, latencia Sheets 1.5-3 seg, persistencia 5/5 reinicios, HTTP 200 OK confirmado, y tabla de validación contra problema del Avance #1
2026-06-25 Actualiza README principal testing con resultados reales
    Agrega tabla de resultados reales: 90% precisión entrada, 80% salida, 100% persistencia, latencia Sheets 1.5-3 seg, y tabla de validación contra problema del Avance #1
2026-06-25 Actualiza README reportes con resultados reales de pruebas
    Completa tabla de resultados con datos reales del protocolo: 91.4% precisión global, 9/10 entradas, 8/10 salidas, 5/5 persistencia y timeout, HTTP 200 OK confirmado
2026-06-25 Mejora README iteración 2 con datos reales y conexión a v4 final
    Agrega nota sobre GPIO conflictivos latentes en v2, marca problemas pendientes como resueltos en v4 con datos reales, y confirma ejecución del plan de mejora con resultados obtenidos
2026-06-25 Mejora README iteración 1 con contexto real y conexión a versiones posteriores
    Agrega contexto del Avance #1 con datos encuesta, marca 4 problemas como resueltos con versión donde se ejecutó la solución, y agrega tabla comparativa v1-v2-v4 con datos reales
    ¿Qué queda pendiente después de esto?
2026-06-25 Actualiza README principal iteraciones con historial completo SIMA
    Agrega tabla comparativa real v1-v2-v4, evolución narrativa de las 3 versiones, justificación de cambios hardware/software/3D con datos reales, incorporación de feedback de evaluadores, y métricas de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
2026-06-25 Agrega foto interior del prototipo SIMA
    Vista interior con tapa removida mostrando batería Li-ion NCR18650B, ESP32-S3 y cableado — evidencia del diseño para reparación en campo
2026-06-25 Agrega foto lateral del prototipo SIMA
    Vista lateral del encapsulado mostrando orificio USB-A para carga de batería y orificios de tornillos para fijación de tapa
2026-06-25 Delete documentacion/presentacion/README.md
    Se elimina el README para agregar la verdadera presentación
2026-06-25 Agrega reporte final SIMA v1
    Reporte completo de 12 páginas: resumen ejecutivo, introducción con datos encuesta Avance #1, marco teórico ODS 11, metodología, diseño hardware/software/3D, 3 iteraciones documentadas, protocolo de 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
2026-06-25 Actualiza README principal con nombre SIMA y datos reales del proyecto
    Agrega nombre SIMA, precisión 91.4%, tabla de resultados de validación, diseño de dos módulos, roles actualizados, estructura real del repo con subcarpetas, estado del proyecto corregido y columna de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
2026-06-25 Actualiza FUENTES.md con declaración completa de IA en código y documentación
    Agrega sección 3.9 (comentarios firmware), sección 4 completa (documentación generada con IA: READMEs, reporte PDF, diálogos, protocolo de pruebas, guía Fusion 360) y tablas de resumen actualizadas
